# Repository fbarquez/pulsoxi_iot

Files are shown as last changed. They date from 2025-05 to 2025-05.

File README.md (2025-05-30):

# IoT-Based Pulse Oximeter with PIC16F1936/37 and ESP32











---

## Project Overview

This repository presents the development of a **microcontroller-based pulse oximeter** with wireless data transmission via Wi-Fi, intended for remote health monitoring. The system was designed as part of a Bachelor's thesis in **Information and Communication Technology Engineering** at HTW Berlin.

It measures **SpO₂ (blood oxygen saturation)** and **BPM (heart rate)** using optical sensing and analog signal conditioning. A **PIC16F1937** microcontroller digitizes the signals and transmits them via UART to an **ESP32-C6**, which uploads the data to **ThingSpeak** for real-time cloud visualization.

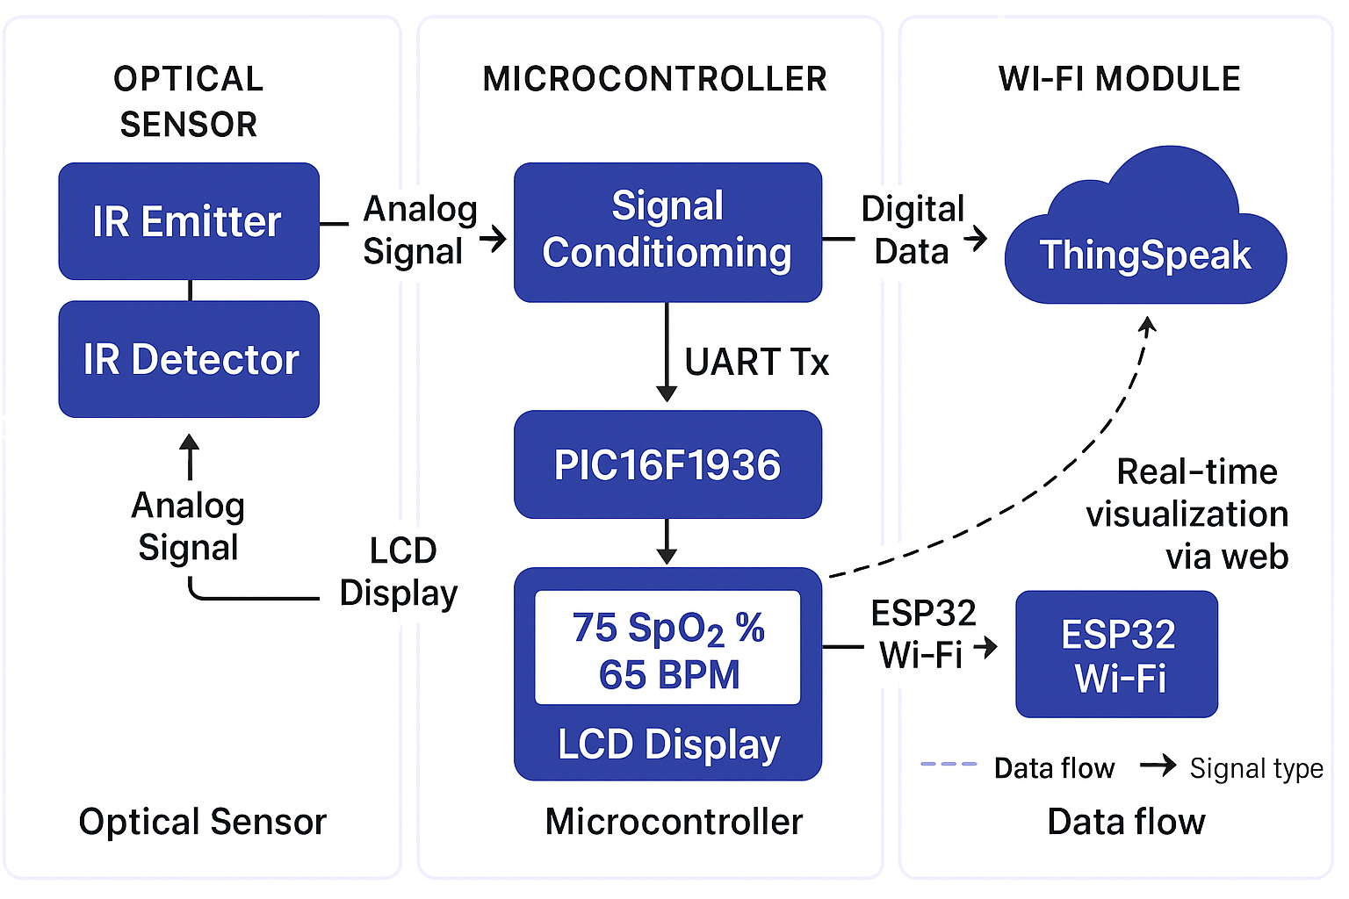
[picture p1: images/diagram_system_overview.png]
Project Overview


---

**View Full Thesis (Web Viewer)**: 
[Read the full thesis as images](https://fbarquez.github.io/pulsoxi_iot/thesis/index.html)

**Live Demonstration Video**: 
[▶ Watch on Dropbox](https://www.dropbox.com/scl/fi/jzmq0wq67i9w6cfi0vw9p/FernandoBarrigaVasquez_videodesProjekts.mp4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)

---

## Features

- Real-time SpO₂ and BPM measurement
- Modular signal processing: sensor input, analog conditioning, digitization
- Wireless data transmission via ESP32 and Wi-Fi
- ThingSpeak dashboard with live charts
- Local LCD display for instant readings
- Custom-designed PCBs using EAGLE

---

## Folder Structure

```
├── docs/                  # Thesis report and web materials
├── firmware/              # Embedded code for PIC and ESP32
│   ├── pic/
│   └── esp32/
├── hardware/              # Schematics and PCB files
├── images/                # Photos and diagrams
├── LICENSE
├── NOTICE.md
├── README.md
└── requirements.md
```

---

## System Architecture

The system is divided into three functional modules:
...

### 1. Analog Front-End (AFE)
- **Components**: IR + Red LEDs, BPW34 photodiode
- **Signal Conditioning**: Low-pass/high-pass filters, current-to-voltage converter, amplifier

### 2. Microcontroller Unit (MCU)
- **Microcontroller**: PIC16F1937 with ADC and UART
- **Tasks**: Signal digitization, data formatting, LCD display update

### 3. Connectivity & Visualization
- **ESP32-C6**: UART receiver, Wi-Fi client
- **Cloud**: ThingSpeak channel for live plotting

---

## Hardware Design

The hardware was developed using **Autodesk EAGLE** and includes:

- Modular PCBs for:
  - Signal conditioning
  - Optical sensor input
  - Power regulation
- Schematic and board files (`.sch` / `.brd`) available in `hardware/eagle/`
- Rendered images and PDFs in `hardware/pdf/`

---

## Firmware and Software

### PIC16F1937 Firmware

- Developed in C using **MPLAB X IDE** with **MCC**
- Core features:
  - ADC configuration
  - UART transmission to ESP32
  - LCD driver integration

 Path: `firmware/pic/oxi_spo2_firmware/`

### ESP32 UART Receiver

- Written in **Arduino framework**
- Connects via UART to PIC
- Transmits data to ThingSpeak over Wi-Fi

 Path: `firmware/esp32/usart_relay_thingspeak.ino`

---

## Data Transmission & Visualization

- **ThingSpeak** IoT platform:
  - Channel with 2 fields: SpO₂ (%) and BPM
  - Real-time data plotted in the dashboard

- **LCD Output**:
  - Displays BPM and oxygen level locally

---

## Requirements

- [MPLAB X IDE](https://www.microchip.com/en-us/tools-resources/develop/mplab-x-ide)
- [MCC (Code Configurator)](https://www.microchip.com/mplab/mplab-code-configurator)
- [Arduino IDE](https://www.arduino.cc/en/software)
- ESP32 board support package
- [ThingSpeak account](https://thingspeak.com)

---

## Usage Instructions

### 1. Clone the repository

```bash
git clone https://github.com/yourusername/SpO2-Monitor-Project.git
cd SpO2-Monitor-Project
```

### 2. PIC Firmware

- Open `firmware/pic/oxi_spo2_firmware/` in MPLAB X
- Compile and flash to the PIC16F1937

### 3. ESP32 Code

- Open `firmware/esp32/usart_relay_thingspeak.ino` in Arduino IDE
- Configure your Wi-Fi credentials and ThingSpeak API key
- Upload to your ESP32 board

### 4. Dashboard

- Access your ThingSpeak channel to monitor live data
- Optionally view readings on the 16x2 LCD display

---

## License & Legal

This repository is provided **for educational and demonstration purposes only**.

> Not licensed for reuse, redistribution, or commercial use.

All content © 2024 fbarquez. 
See [`LICENSE`](LICENSE) for more details.

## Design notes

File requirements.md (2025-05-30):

# Project Requirements

This document lists all the tools, libraries, and platforms required to build, upload, and run the Pulse Oximeter project.

---

## Hardware Requirements

- **Microcontroller**: PIC16F1937
- **Wi-Fi Module**: ESP32-C6
- **Sensors**:
  - BPW34 photodiode
  - IR and RED LEDs
- **Display**: 16x2 LCD (HD44780 compatible)

---

## Development Tools

### For PIC16F1937 (Firmware)

- [MPLAB X IDE](https://www.microchip.com/en-us/tools-resources/develop/mplab-x-ide) (v6.0 or later)
- [MPLAB XC8 Compiler](https://www.microchip.com/en-us/tools-resources/develop/mplab-xc-compilers) (v2.40 or later)
- [MCC - MPLAB Code Configurator](https://www.microchip.com/mplab/mplab-code-configurator)

### For ESP32 (Wi-Fi Transmitter)

- [Arduino IDE](https://www.arduino.cc/en/software) (v2.0 or later)
- ESP32 Board Support via Board Manager  
  (Install via: `https://raw.githubusercontent.com/espressif/arduino-esp32/gh-pages/package_esp32_index.json`)
- Required Arduino libraries:
  - `WiFi.h`
  - `HTTPClient.h`

---

## Hardware Design

- [Autodesk EAGLE](https://www.autodesk.com/products/eagle/overview) (v9.6 or later)

---

## Online Services

- [ThingSpeak](https://thingspeak.com) IoT platform
  - One channel with at least 2 fields: SpO₂ and BPM
  - Optional: API Key for write access

- [GitHub Pages](https://pages.github.com/) for hosting the presentation page (optional)

---

## Optional Tools

- [Proteus / LTspice / Falstad] (for circuit simulation if used during development)
- [Markdown Preview](https://marketplace.visualstudio.com/items?itemName=shd101wyy.markdown-preview-enhanced) (for README visualization)

---

## Notes

- Ensure all USB drivers for PICkit or ESP32 are properly installed.
- Internet access is required for data upload to ThingSpeak.

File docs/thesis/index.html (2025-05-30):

# Bachelor Thesis: IoT Pulse Oximeter

Presented by fbarquez – HTW Berlin, 2024

This viewer displays each page of the thesis as an image with watermarks for privacy.

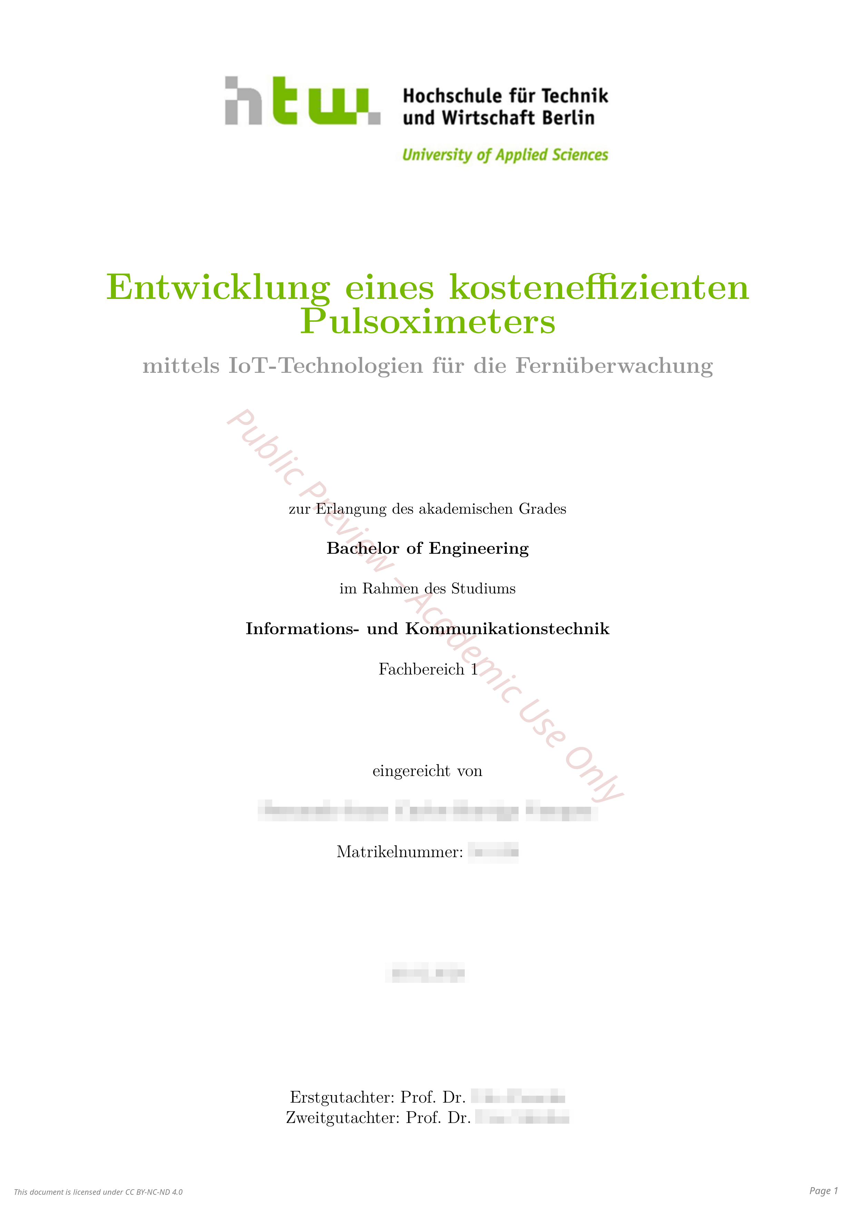
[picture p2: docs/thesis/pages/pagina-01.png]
Thesis page 1 – Pulse Oximeter Project
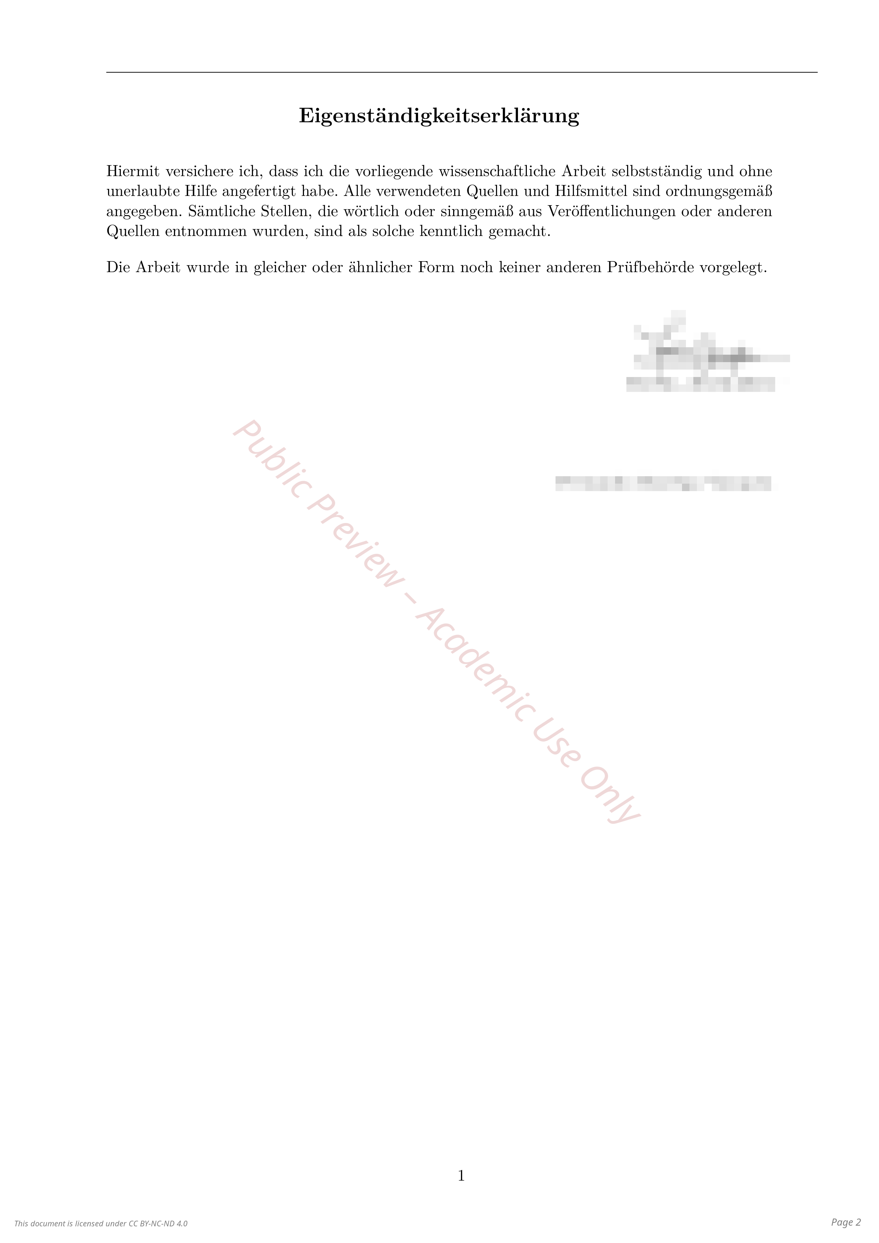
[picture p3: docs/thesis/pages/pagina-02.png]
Thesis page 2 – Pulse Oximeter Project
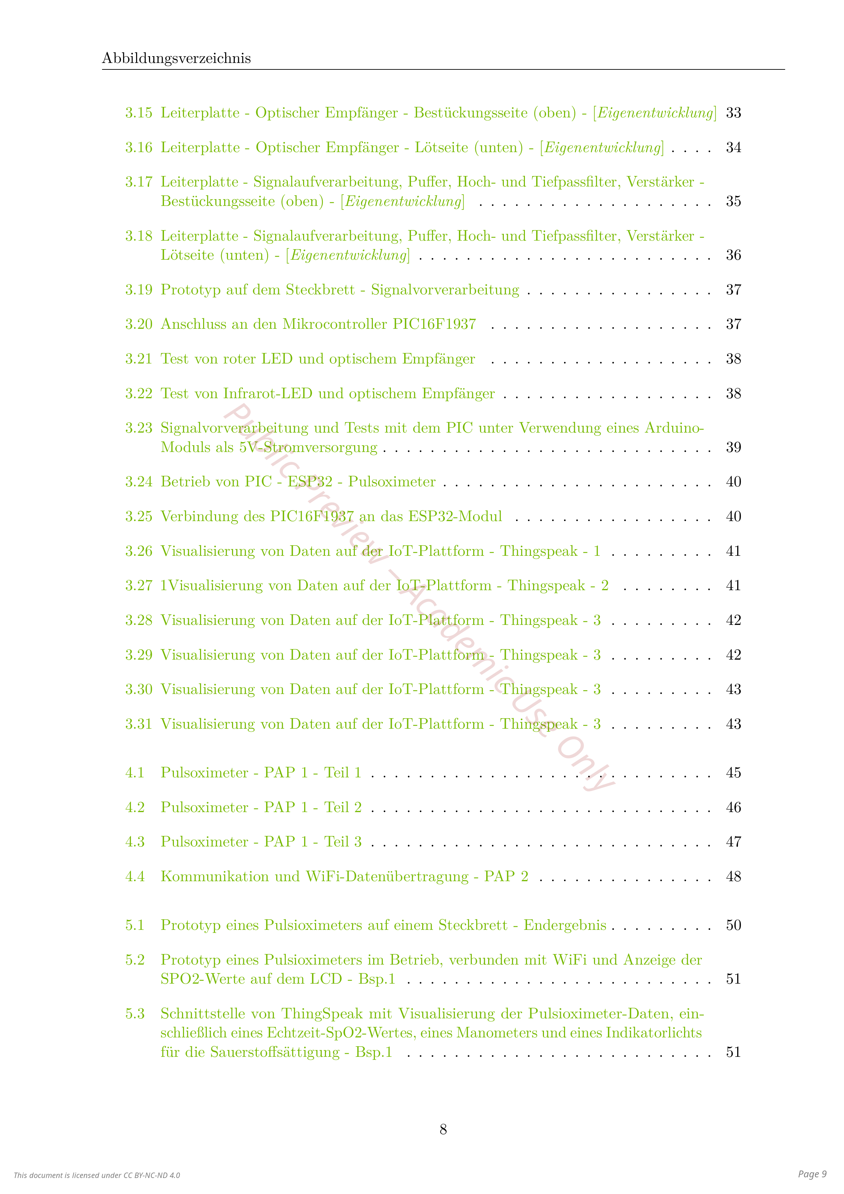
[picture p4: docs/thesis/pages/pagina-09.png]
Thesis page 9 – Pulse Oximeter Project
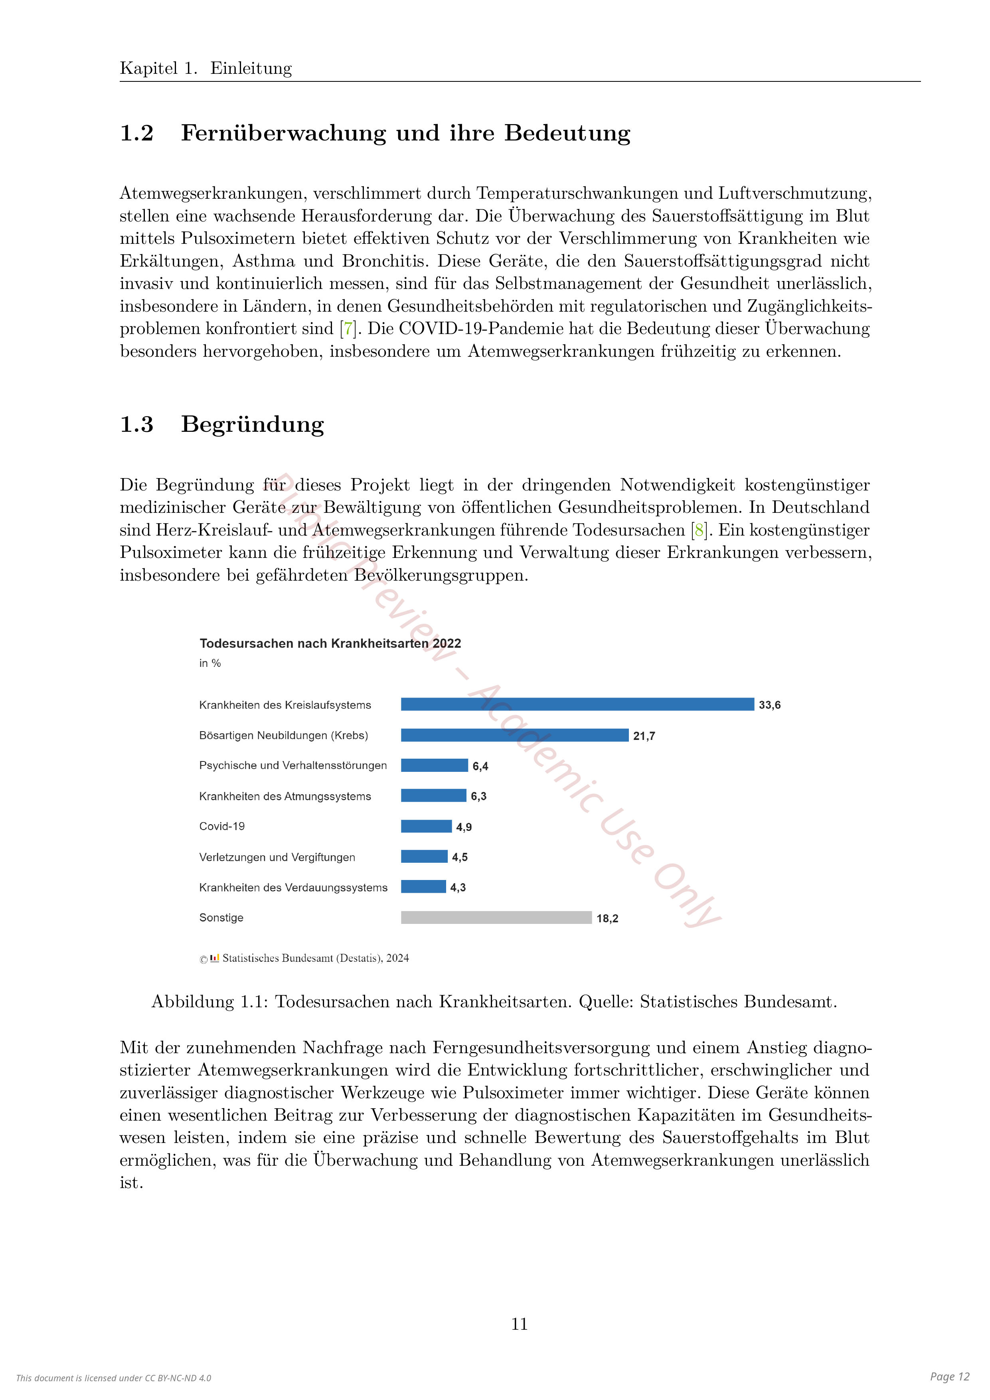
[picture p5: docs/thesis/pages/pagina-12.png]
Thesis page 12 – Pulse Oximeter Project
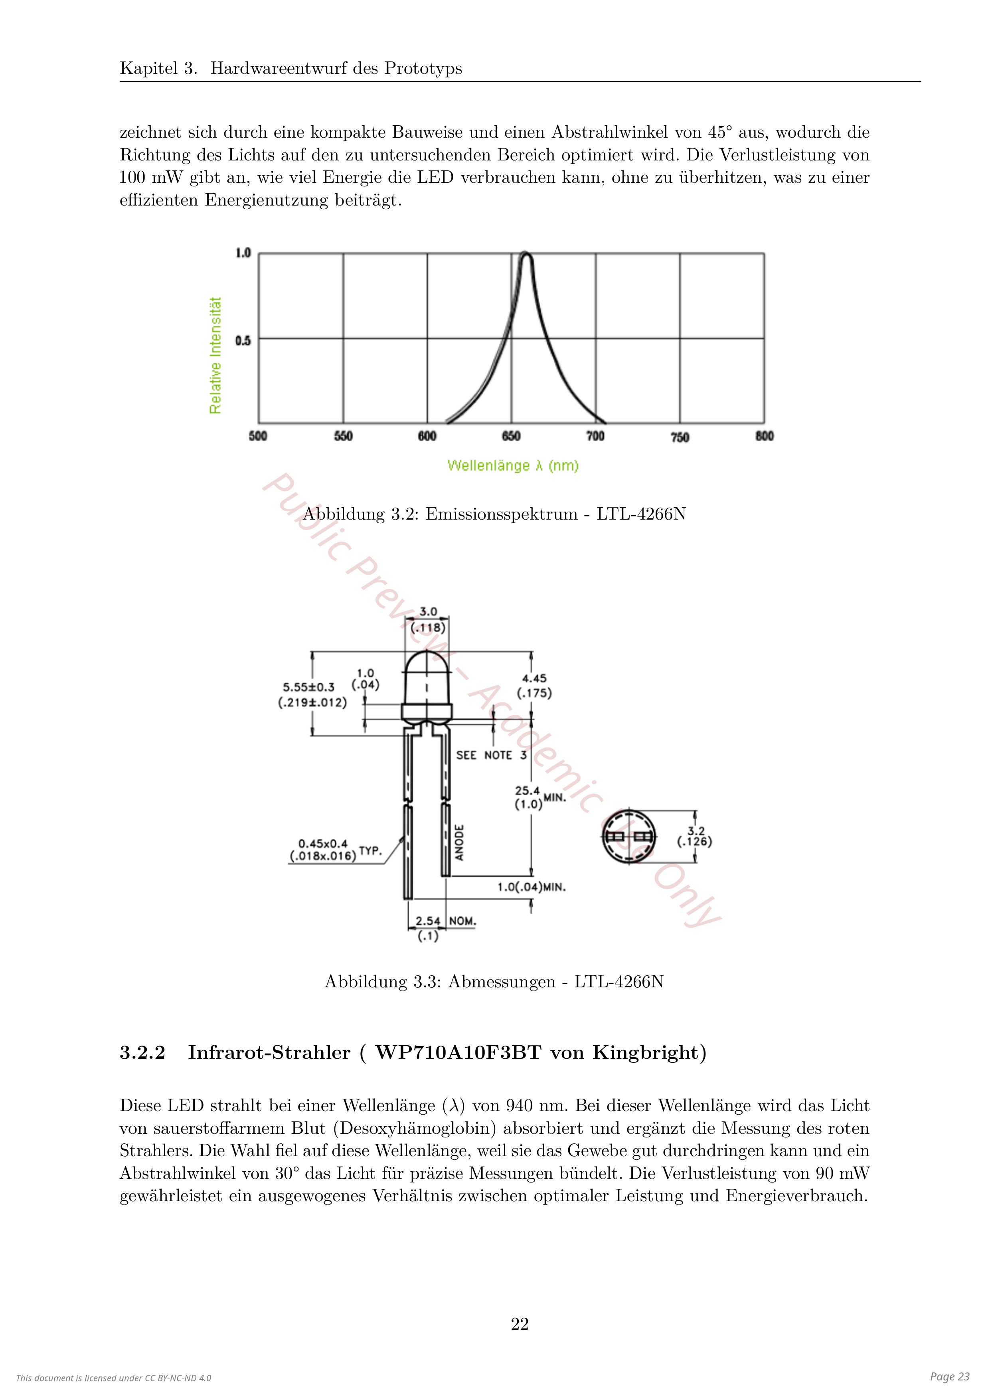
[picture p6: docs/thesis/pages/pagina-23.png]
Thesis page 23 – Pulse Oximeter Project
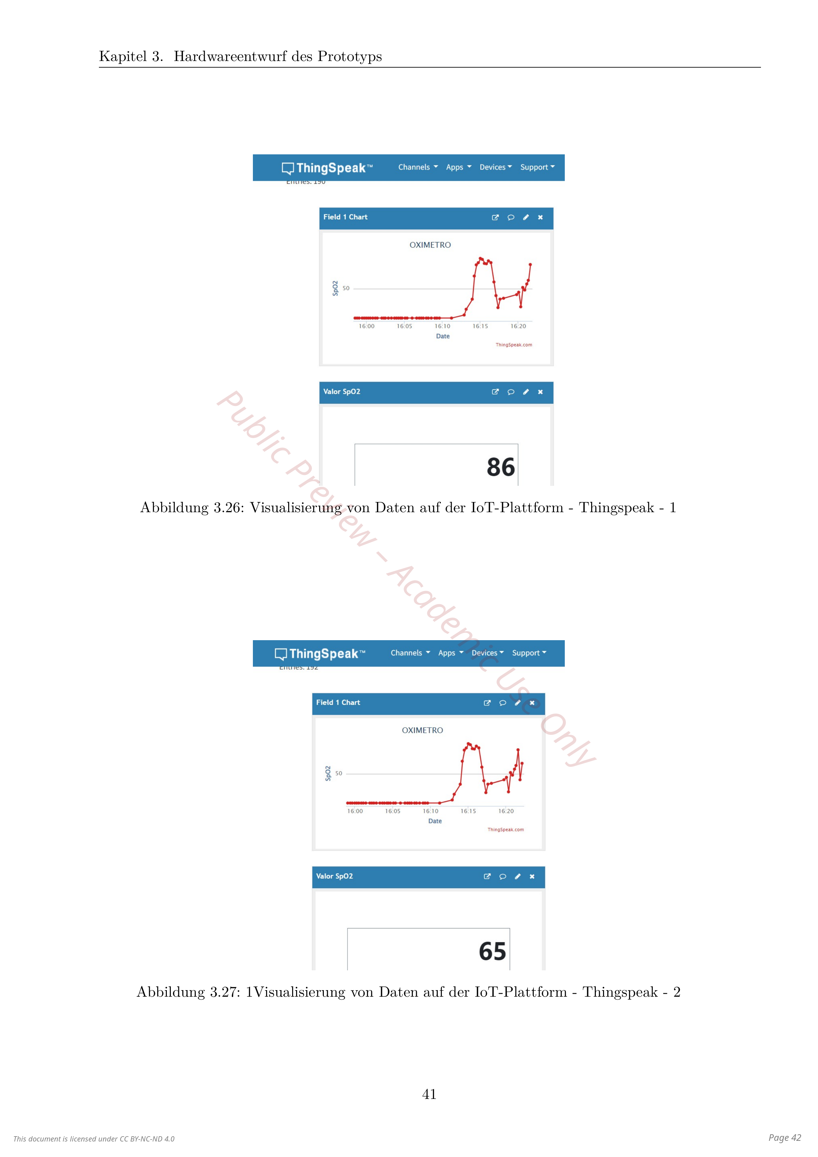
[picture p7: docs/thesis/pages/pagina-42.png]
Thesis page 42 – Pulse Oximeter Project
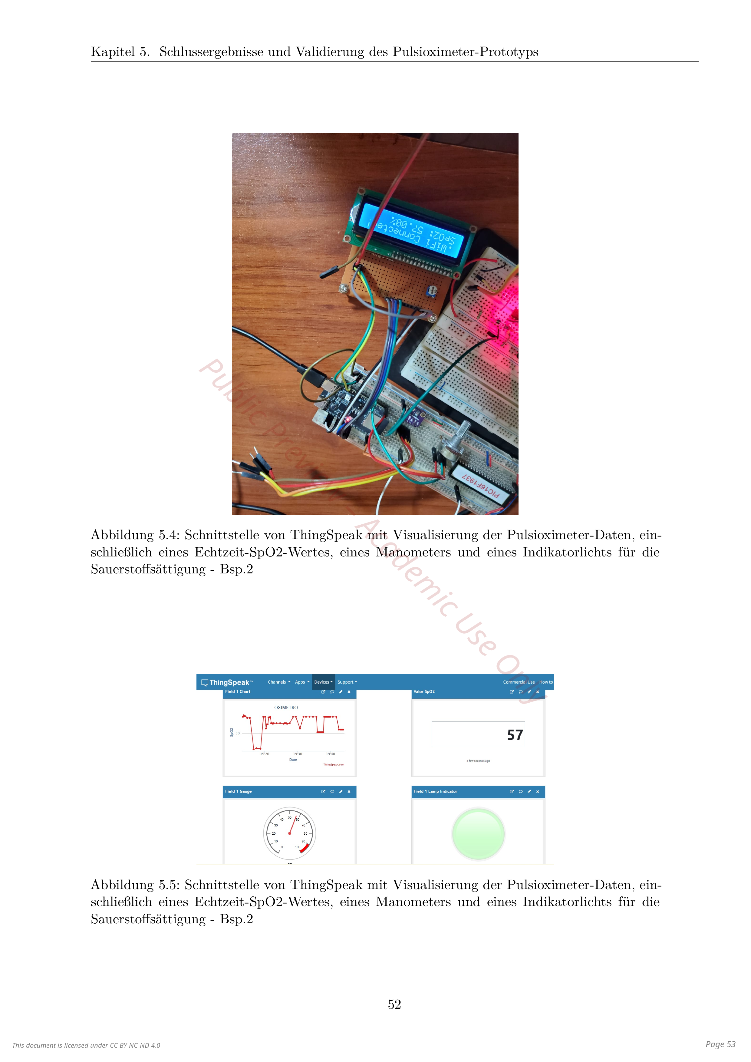
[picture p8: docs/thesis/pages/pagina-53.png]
Thesis page 53 – Pulse Oximeter Project
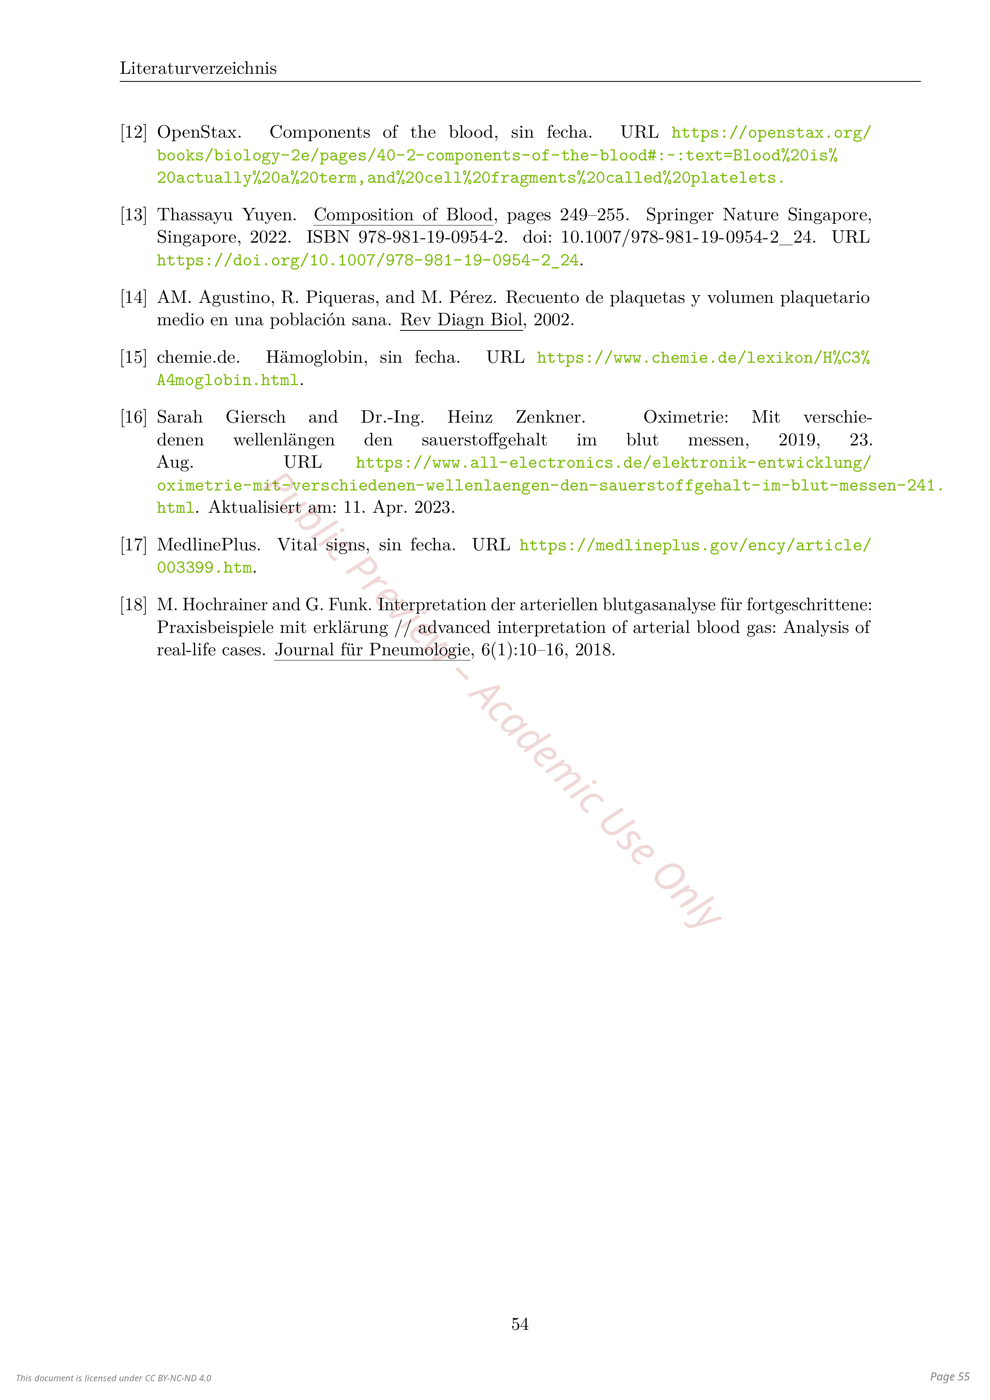
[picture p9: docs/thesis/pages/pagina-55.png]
Thesis page 55 – Pulse Oximeter Project
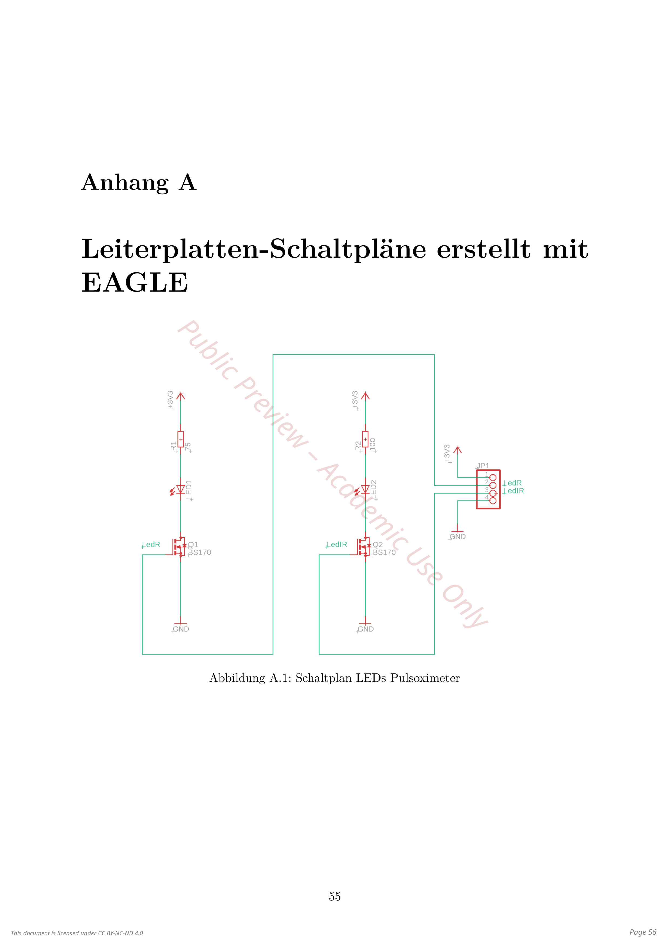
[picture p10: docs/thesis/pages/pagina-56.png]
Thesis page 56 – Pulse Oximeter Project
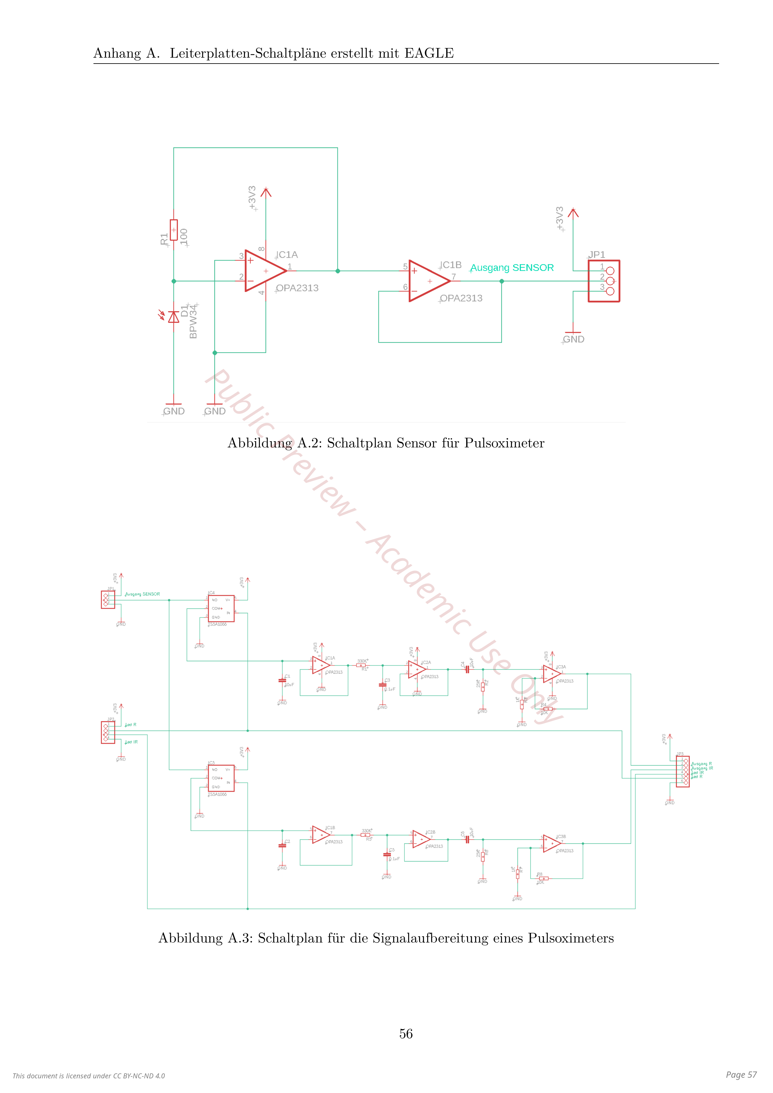
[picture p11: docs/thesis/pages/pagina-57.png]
Thesis page 57 – Pulse Oximeter Project
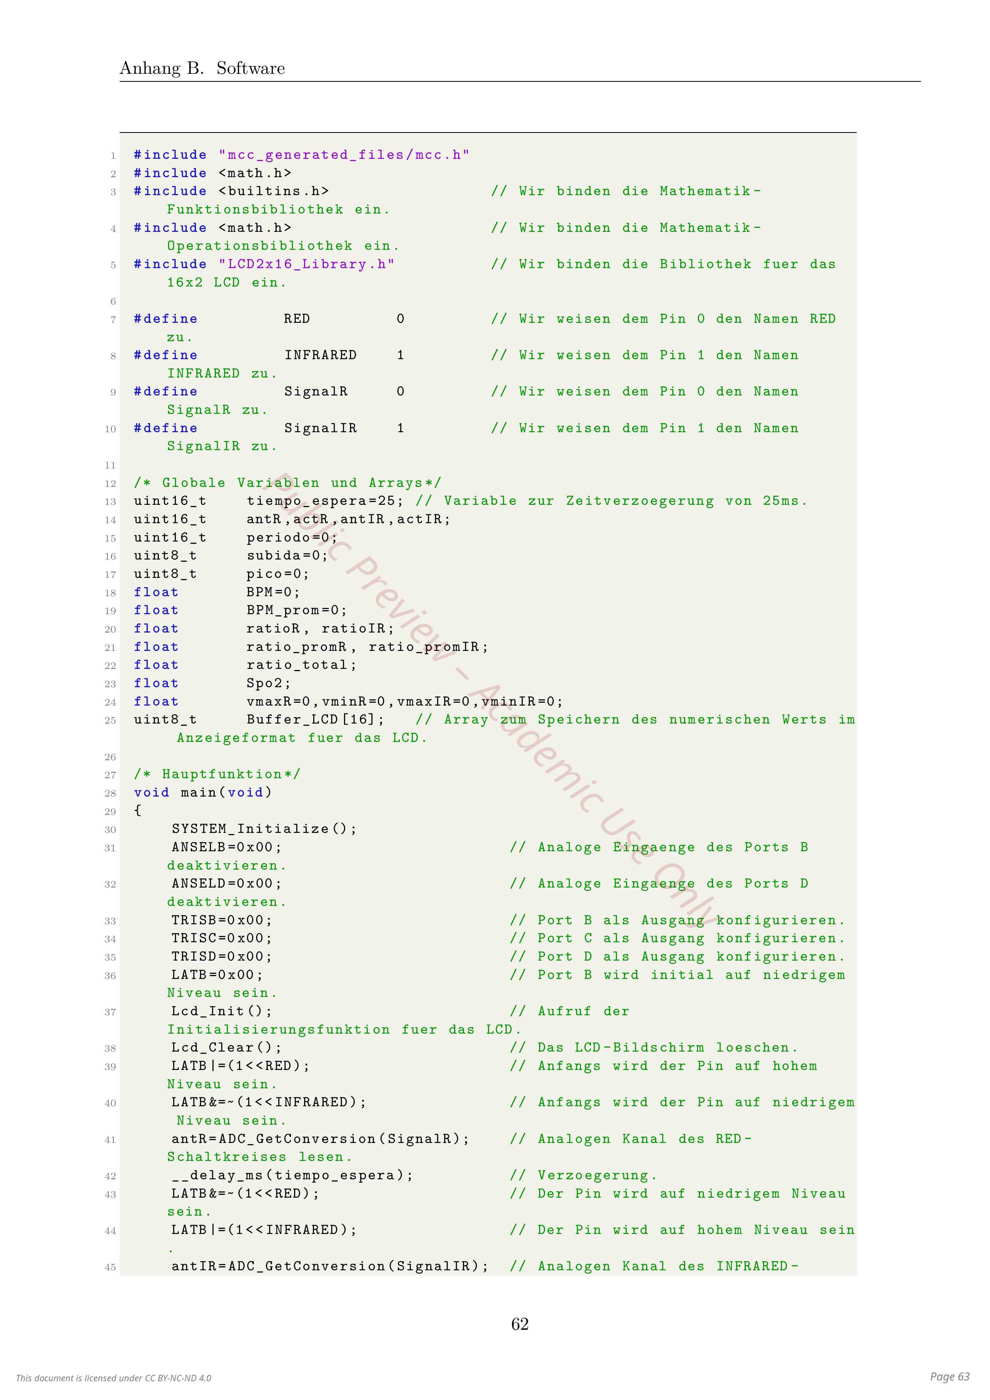
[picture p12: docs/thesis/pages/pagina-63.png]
Thesis page 63 – Pulse Oximeter Project
  Thesis page 3 – Pulse Oximeter Project Thesis page 4 – Pulse Oximeter Project Thesis page 5 – Pulse Oximeter Project Thesis page 6 – Pulse Oximeter Project Thesis page 7 – Pulse Oximeter Project Thesis page 8 – Pulse Oximeter Project  Thesis page 10 – Pulse Oximeter Project Thesis page 11 – Pulse Oximeter Project  Thesis page 13 – Pulse Oximeter Project Thesis page 14 – Pulse Oximeter Project Thesis page 15 – Pulse Oximeter Project Thesis page 16 – Pulse Oximeter Project Thesis page 17 – Pulse Oximeter Project Thesis page 18 – Pulse Oximeter Project Thesis page 19 – Pulse Oximeter Project Thesis page 20 – Pulse Oximeter Project Thesis page 21 – Pulse Oximeter Project Thesis page 22 – Pulse Oximeter Project  Thesis page 24 – Pulse Oximeter Project Thesis page 25 – Pulse Oximeter Project Thesis page 26 – Pulse Oximeter Project Thesis page 27 – Pulse Oximeter Project Thesis page 28 – Pulse Oximeter Project Thesis page 29 – Pulse Oximeter Project Thesis page 30 – Pulse Oximeter Project Thesis page 31 – Pulse Oximeter Project Thesis page 32 – Pulse Oximeter Project Thesis page 33 – Pulse Oximeter Project Thesis page 34 – Pulse Oximeter Project Thesis page 35 – Pulse Oximeter Project Thesis page 36 – Pulse Oximeter Project Thesis page 37 – Pulse Oximeter Project Thesis page 38 – Pulse Oximeter Project Thesis page 39 – Pulse Oximeter Project Thesis page 40 – Pulse Oximeter Project Thesis page 41 – Pulse Oximeter Project  Thesis page 43 – Pulse Oximeter Project Thesis page 44 – Pulse Oximeter Project Thesis page 45 – Pulse Oximeter Project Thesis page 46 – Pulse Oximeter Project Thesis page 47 – Pulse Oximeter Project Thesis page 48 – Pulse Oximeter Project Thesis page 49 – Pulse Oximeter Project Thesis page 50 – Pulse Oximeter Project Thesis page 51 – Pulse Oximeter Project Thesis page 52 – Pulse Oximeter Project  Thesis page 54 – Pulse Oximeter Project    Thesis page 58 – Pulse Oximeter Project Thesis page 59 – Pulse Oximeter Project Thesis page 60 – Pulse Oximeter Project Thesis page 61 – Pulse Oximeter Project Thesis page 62 – Pulse Oximeter Project  Thesis page 64 – Pulse Oximeter Project Thesis page 65 – Pulse Oximeter Project Thesis page 66 – Pulse Oximeter Project Thesis page 67 – Pulse Oximeter Project Thesis page 68 – Pulse Oximeter Project

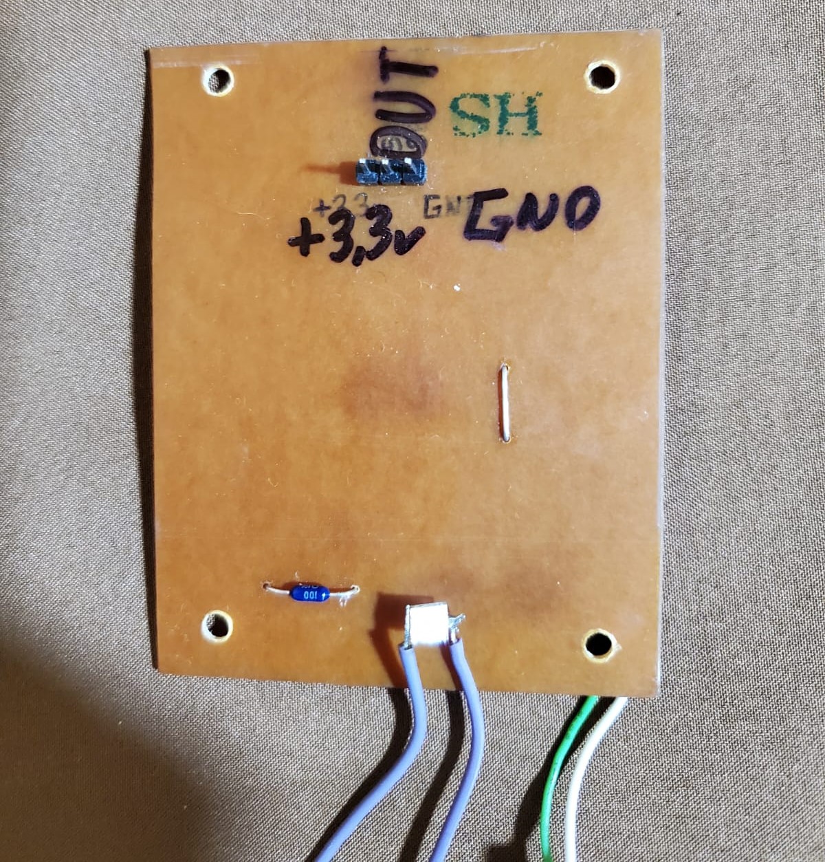
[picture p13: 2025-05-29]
images/PCB/ReceptorOptico_PCB_elaboracionpropia.jpg

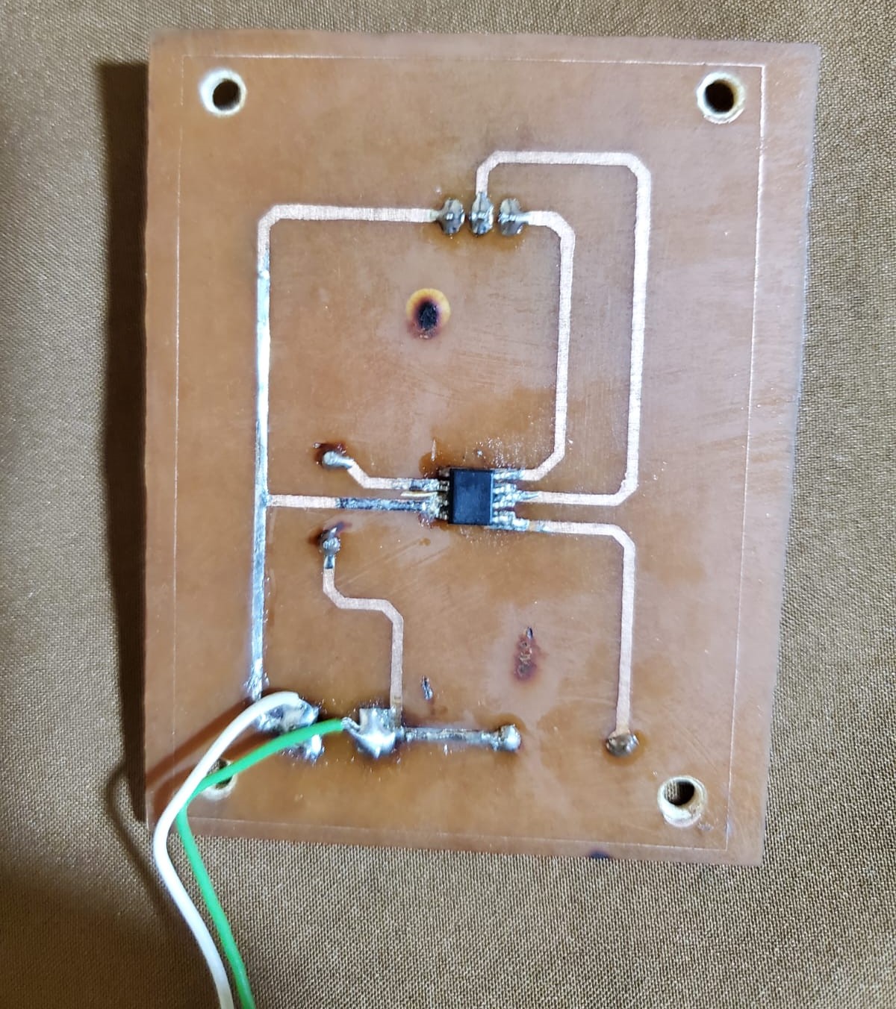
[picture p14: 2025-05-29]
images/PCB/ReceptorOptico_PCB_elaboracionpropia_2.jpg

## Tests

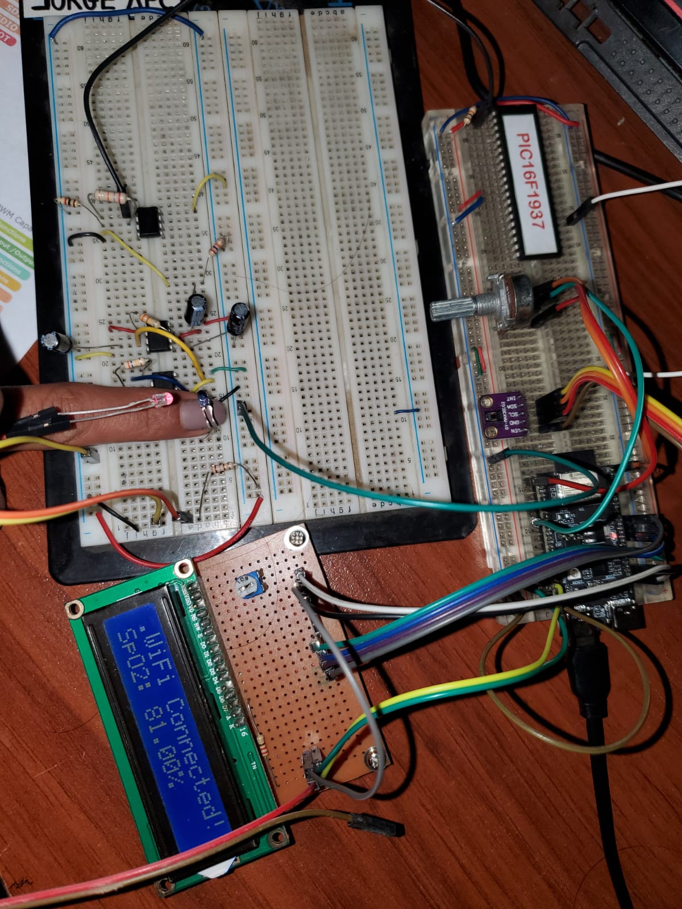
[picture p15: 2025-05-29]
images/pruebadequetodofunciona.jpg

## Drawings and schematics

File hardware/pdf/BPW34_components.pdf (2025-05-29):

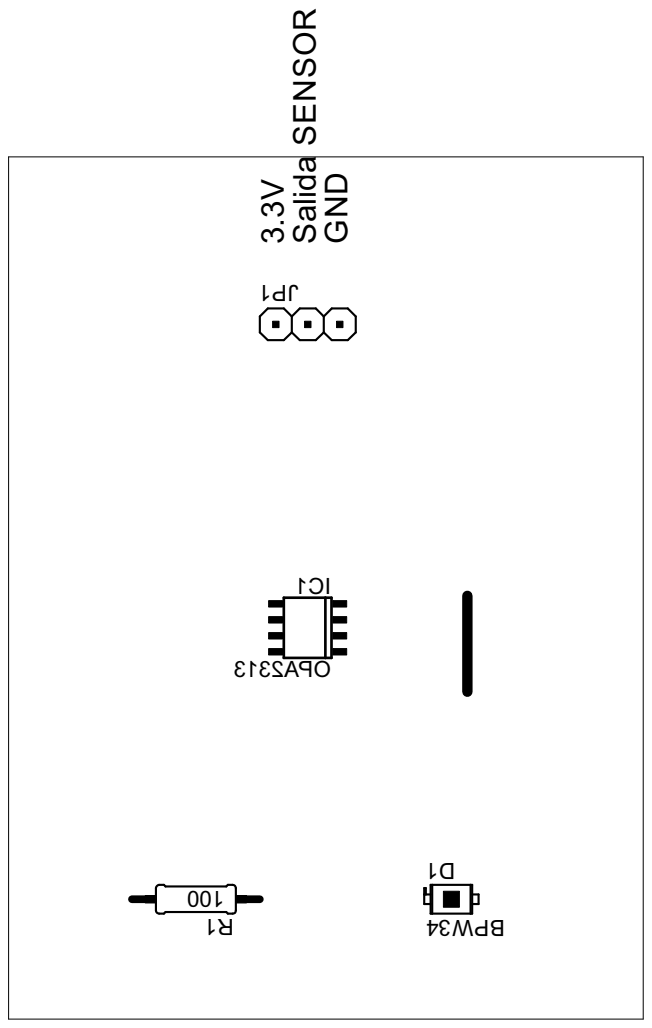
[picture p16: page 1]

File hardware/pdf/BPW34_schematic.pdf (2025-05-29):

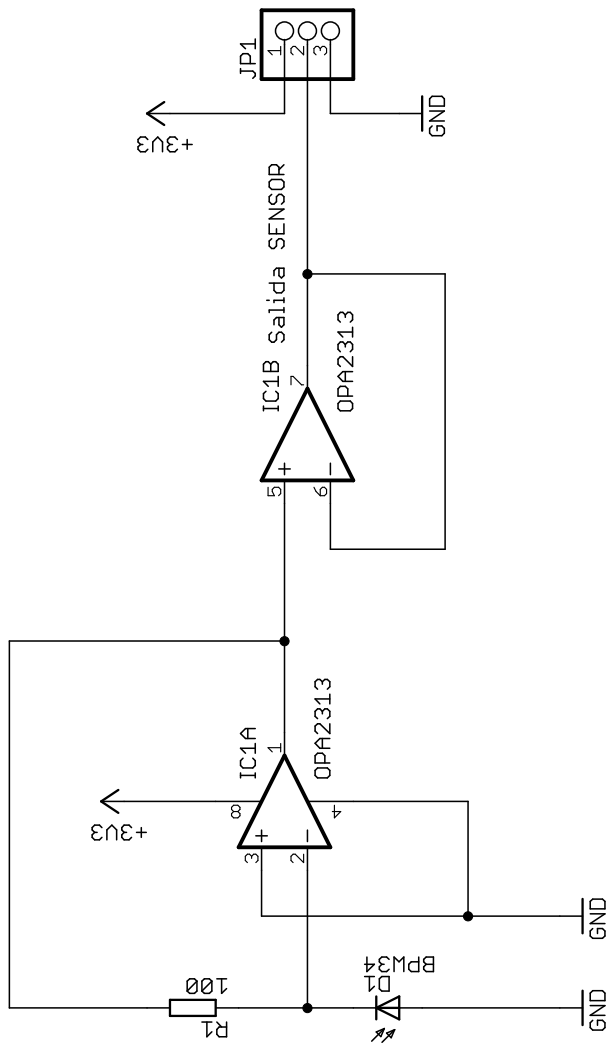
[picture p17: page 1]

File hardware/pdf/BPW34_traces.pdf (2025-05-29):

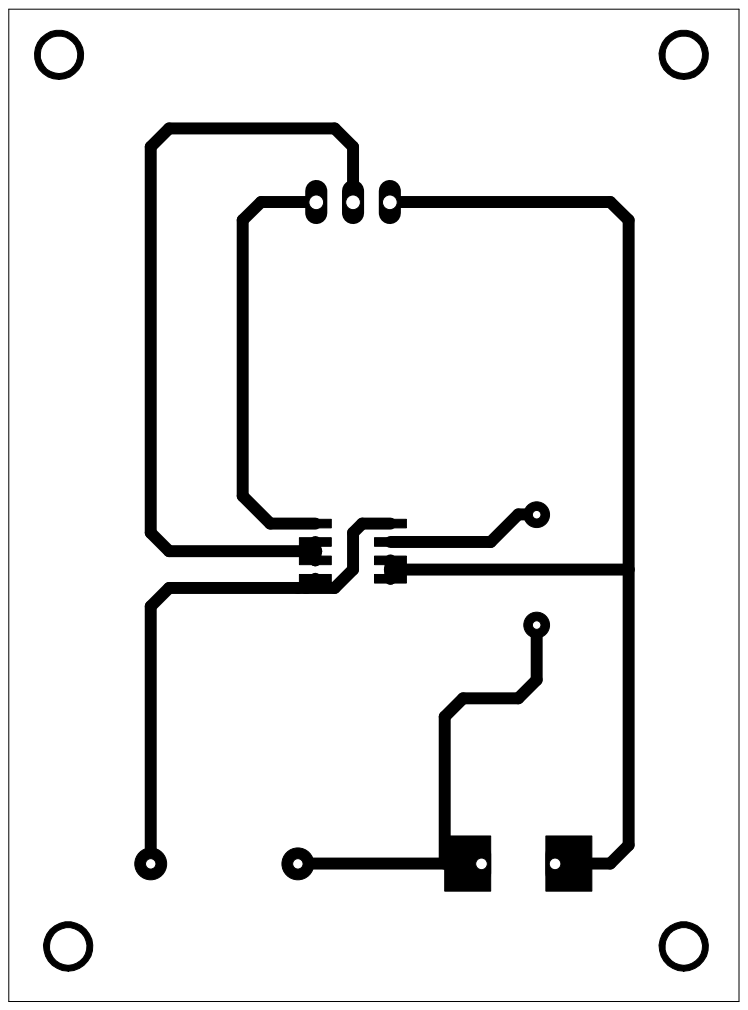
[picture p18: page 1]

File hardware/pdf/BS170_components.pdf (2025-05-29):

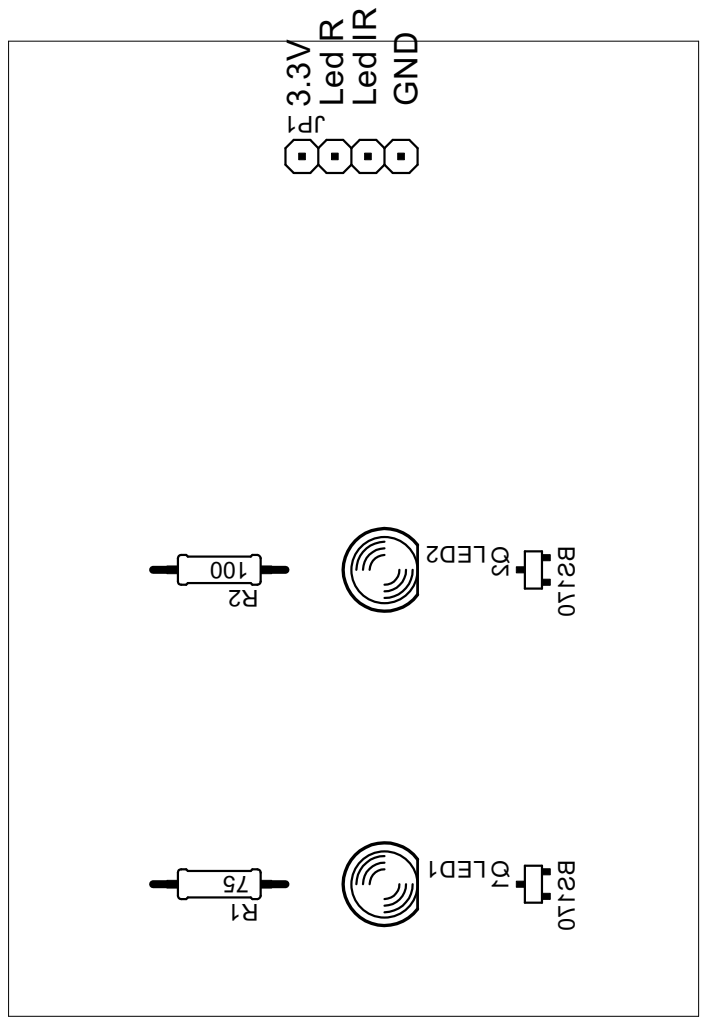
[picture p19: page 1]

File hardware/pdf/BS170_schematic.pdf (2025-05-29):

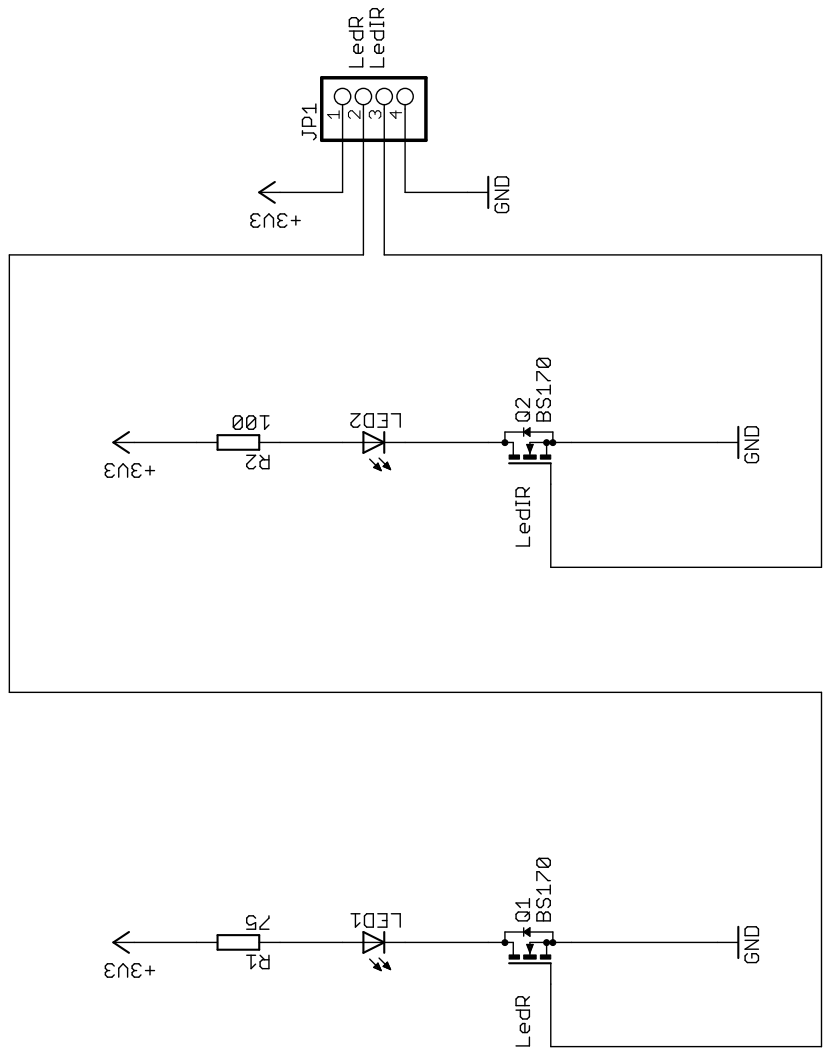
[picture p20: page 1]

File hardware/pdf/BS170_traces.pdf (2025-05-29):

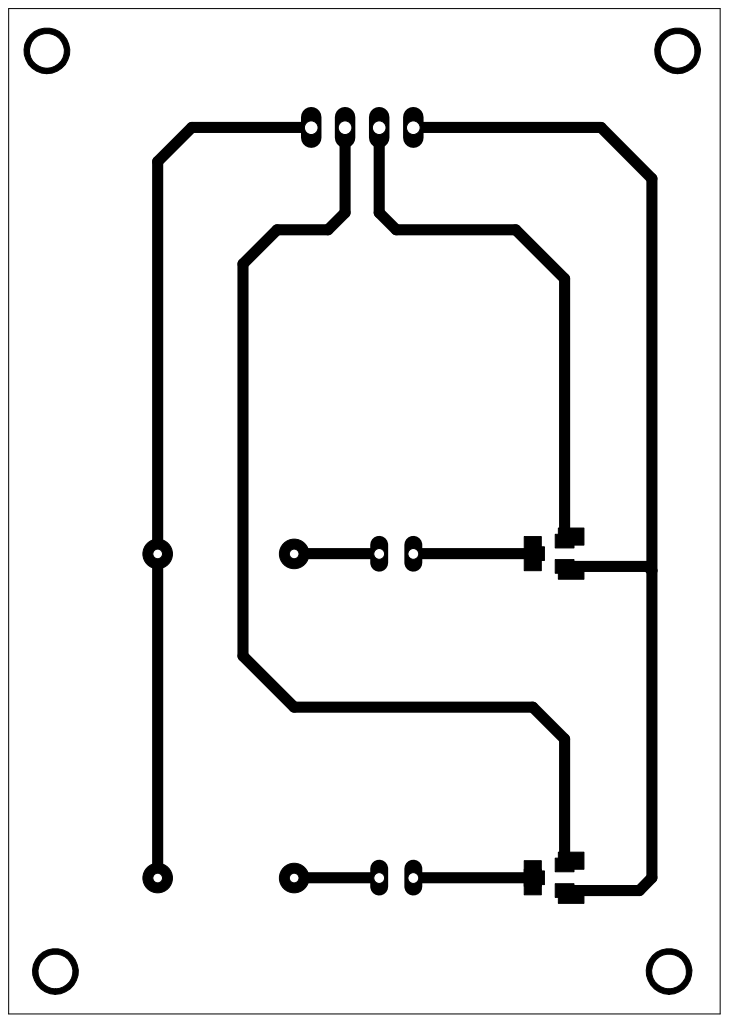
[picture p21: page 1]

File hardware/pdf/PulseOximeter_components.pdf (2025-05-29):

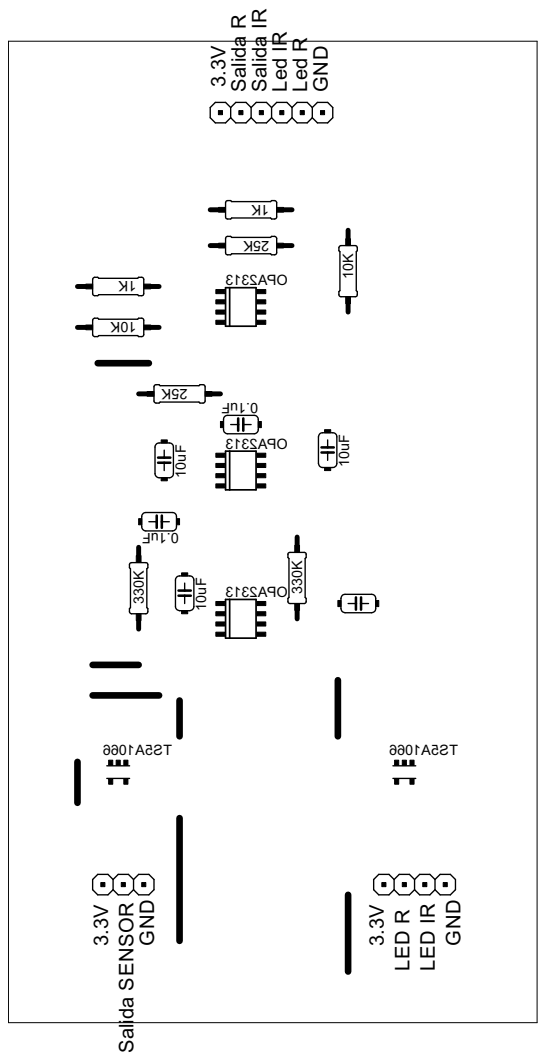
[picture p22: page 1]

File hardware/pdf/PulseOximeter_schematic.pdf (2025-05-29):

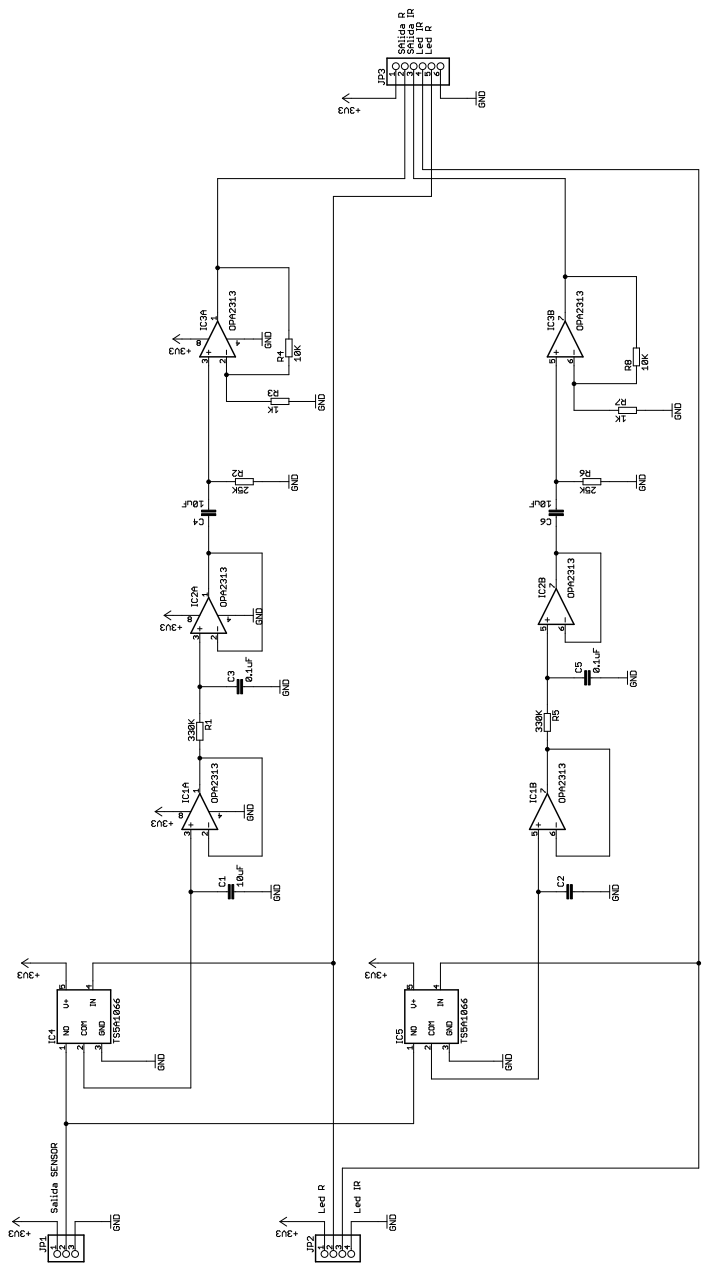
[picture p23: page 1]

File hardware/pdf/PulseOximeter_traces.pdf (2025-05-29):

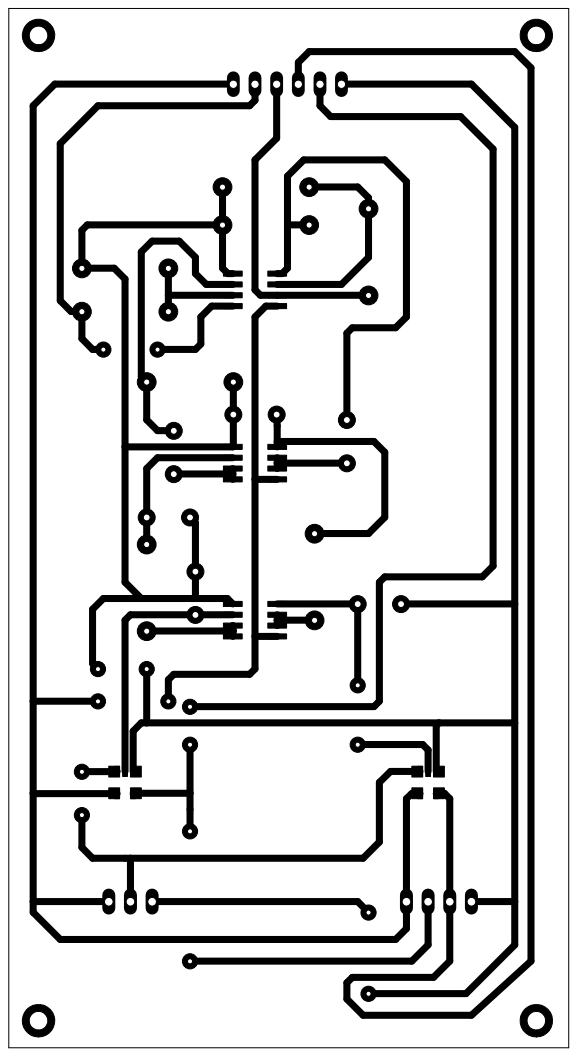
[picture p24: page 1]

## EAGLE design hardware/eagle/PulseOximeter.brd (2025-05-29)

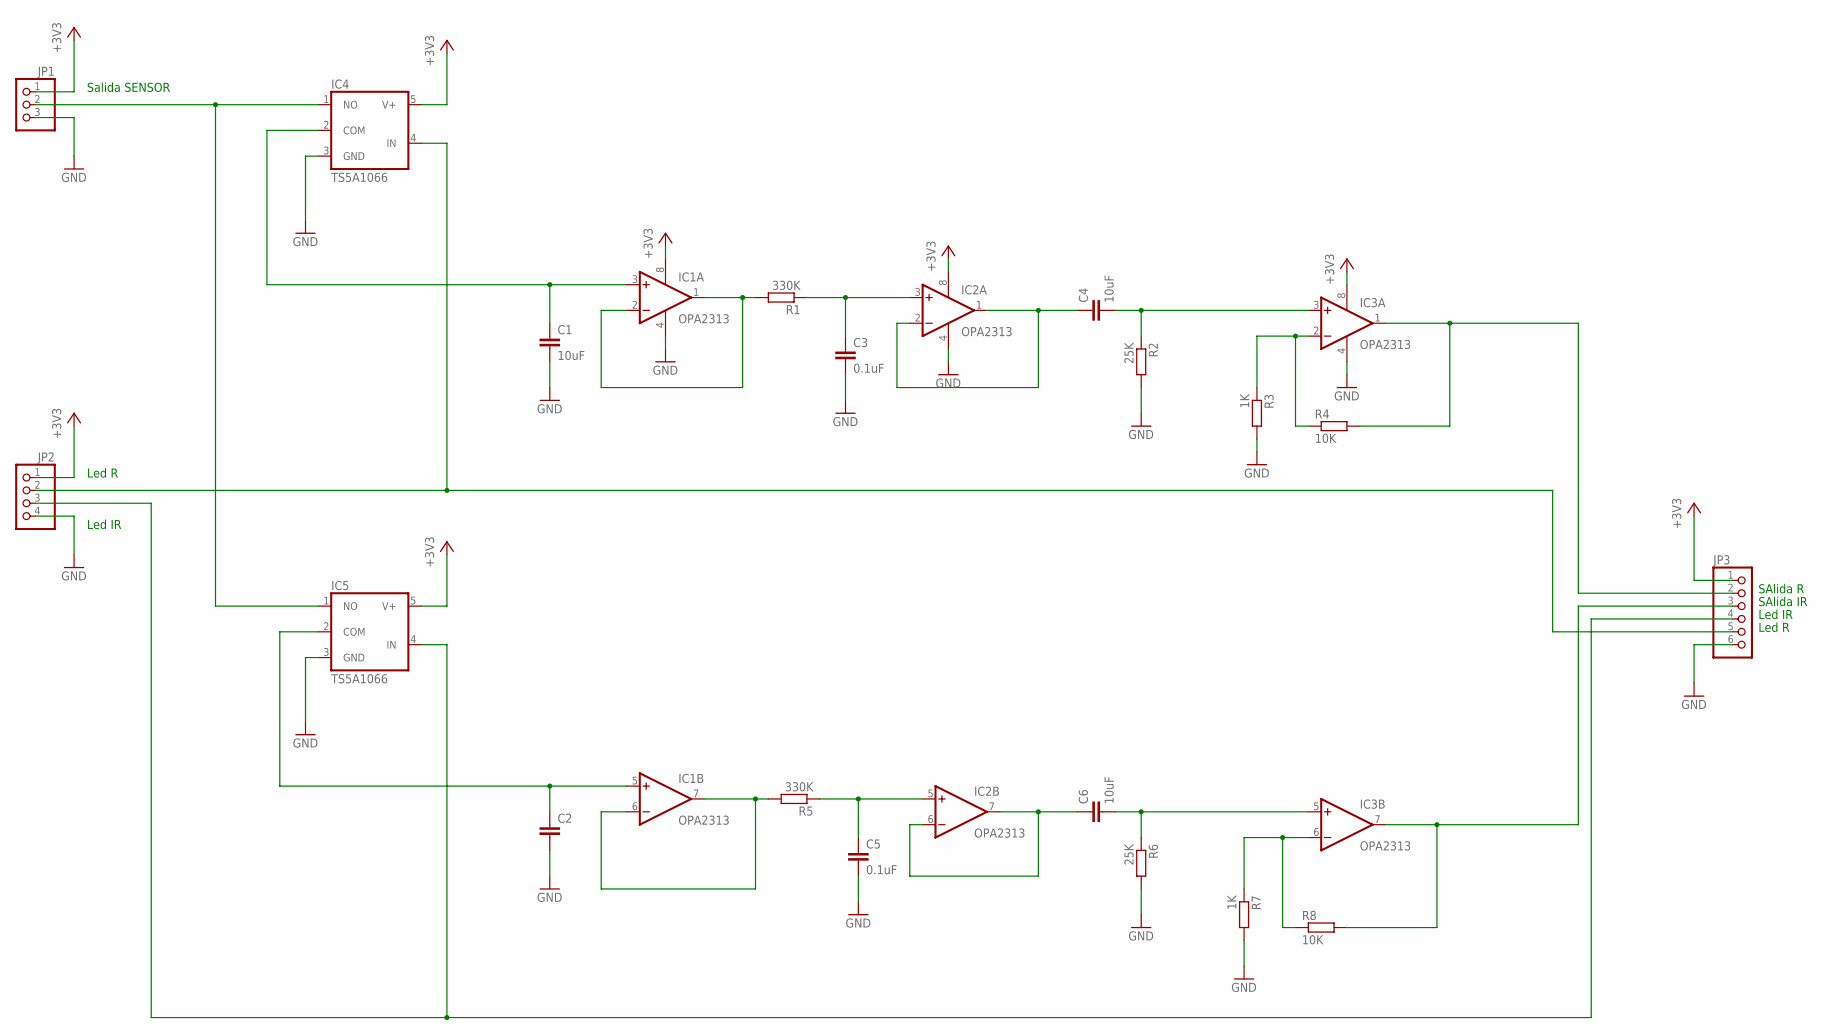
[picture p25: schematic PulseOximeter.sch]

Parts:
C1, C4, C6: 10uF; C050-024X044
C2: C-EU050-024X044; C050-024X044
C3, C5: 0.1uF; C050-024X044
IC1, IC2, IC3: OPA2313; SO08
IC4, IC5: TS5A1066; SOT25
JP1: PINHD-1X3; 1X03
JP2: PINHD-1X4; 1X04
JP3: PINHD-1X6; 1X06
R1, R5: 330K; 0207/10
R2, R6: 25K; 0207/10
R3, R7: 1K; 0207/10
R4, R8: 10K; 0207/10

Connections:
+3V3: IC1.8 (V+), IC2.8 (V+), IC3.8 (V+), IC4.5 (V+), IC5.5 (V+), JP1.1, JP2.1, JP3.1
GND: C1.2, C2.2, C3.2, C5.2, IC1.4 (V-), IC2.4 (V-), IC3.4 (V-), IC4.3 (GND), IC5.3 (GND), JP1.3, JP2.4, JP3.6, R2.2, R3.2, R6.2, R7.2
unnamed: IC4.1 (NO), IC5.1 (NO), JP1.2
unnamed: IC4.4 (IN), JP2.2, JP3.5
unnamed: IC5.4 (IN), JP2.3, JP3.4
unnamed: C1.1, IC1.3 (+IN), IC4.2 (COM)
unnamed: C2.1, IC1.5 (+IN), IC5.2 (COM)
unnamed: C3.1, IC2.3 (+IN), R1.1
unnamed: IC1.1 (OUT), IC1.2 (-IN), R1.2
unnamed: C4.1, IC2.1 (OUT), IC2.2 (-IN)
unnamed: C4.2, IC3.3 (+IN), R2.1
unnamed: IC3.2 (-IN), R3.1, R4.1
unnamed: IC3.1 (OUT), JP3.2, R4.2
unnamed: IC1.6 (-IN), IC1.7 (OUT), R5.2
unnamed: C5.1, IC2.5 (+IN), R5.1
unnamed: C6.1, IC2.6 (-IN), IC2.7 (OUT)
unnamed: C6.2, IC3.5 (+IN), R6.1
unnamed: IC3.6 (-IN), R7.1, R8.1
unnamed: IC3.7 (OUT), JP3.3, R8.2

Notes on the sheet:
Salida SENSOR
Led IR
Led R
SAlida R
SAlida IR

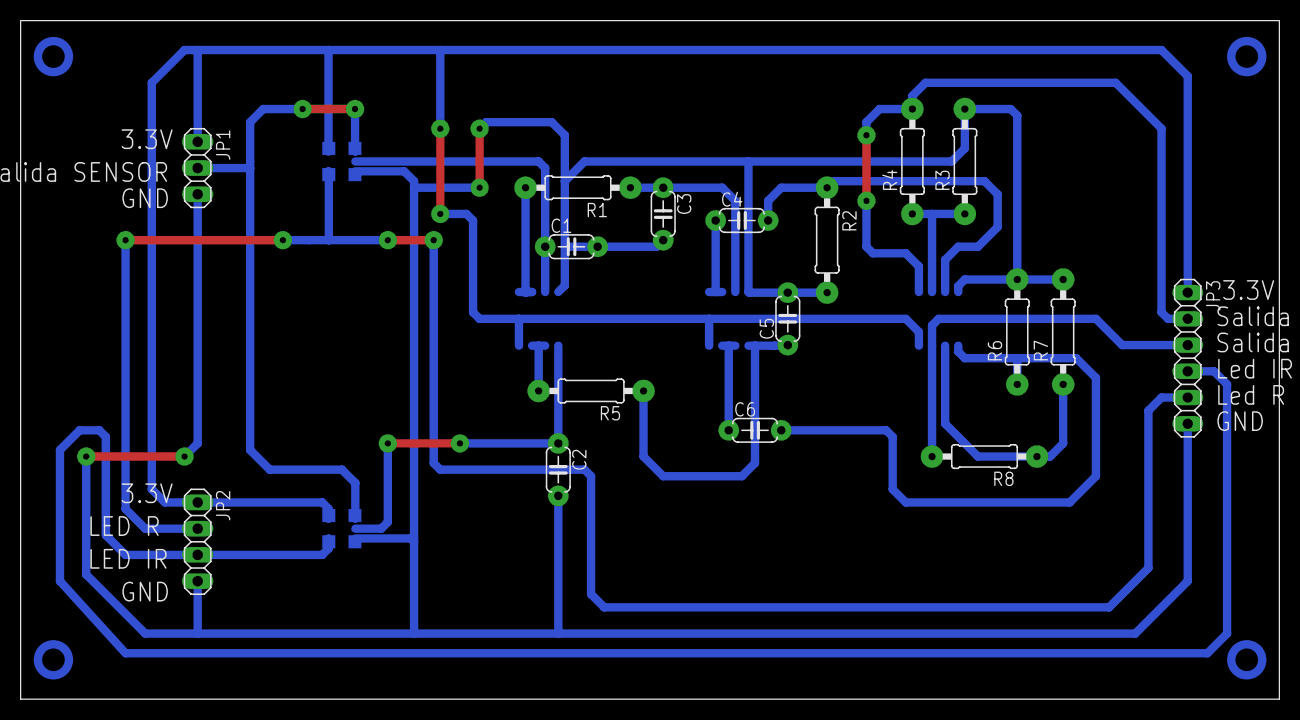
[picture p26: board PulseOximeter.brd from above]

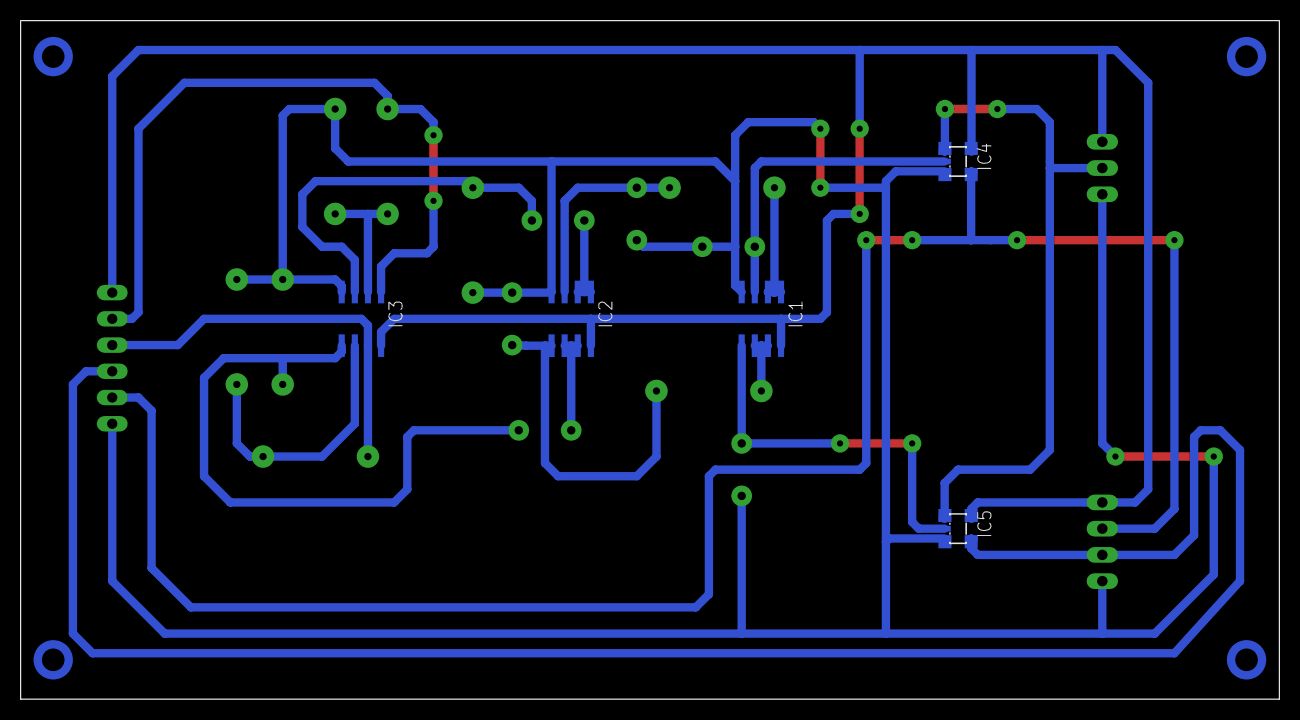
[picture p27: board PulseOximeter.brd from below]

Board: 2 copper layers, 121.9 x 65.7 mm, 22 parts (5 on the bottom side), 19 nets.

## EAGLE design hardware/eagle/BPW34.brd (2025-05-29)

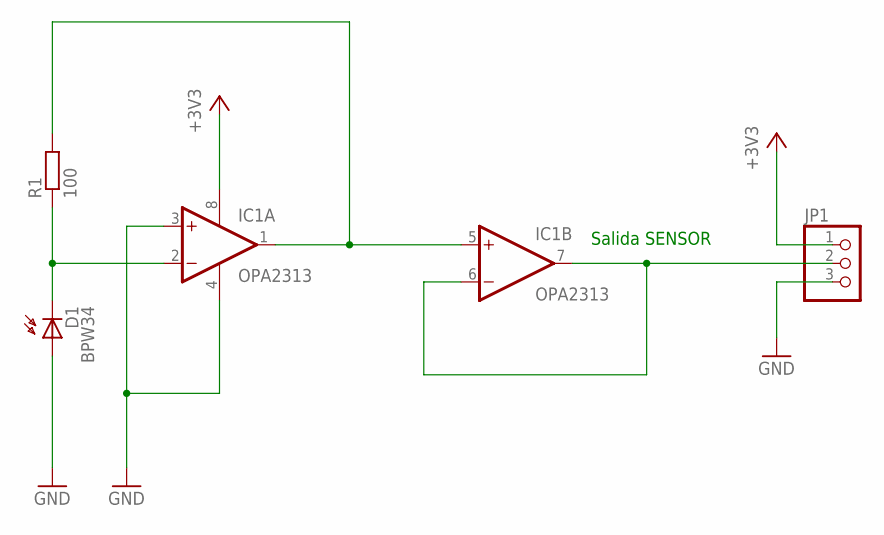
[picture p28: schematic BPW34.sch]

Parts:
D1: BPW34; BPW32
IC1: OPA2313; SO08
JP1: PINHD-1X3; 1X03
R1: 100; 0207/10

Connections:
+3V3: IC1.8 (V+), JP1.1
GND: D1.A, IC1.3 (+IN), IC1.4 (V-), JP1.3
unnamed: IC1.1 (OUT), IC1.5 (+IN), R1.2
unnamed: IC1.6 (-IN), IC1.7 (OUT), JP1.2
unnamed: D1.K (C), IC1.2 (-IN), R1.1

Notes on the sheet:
Salida SENSOR

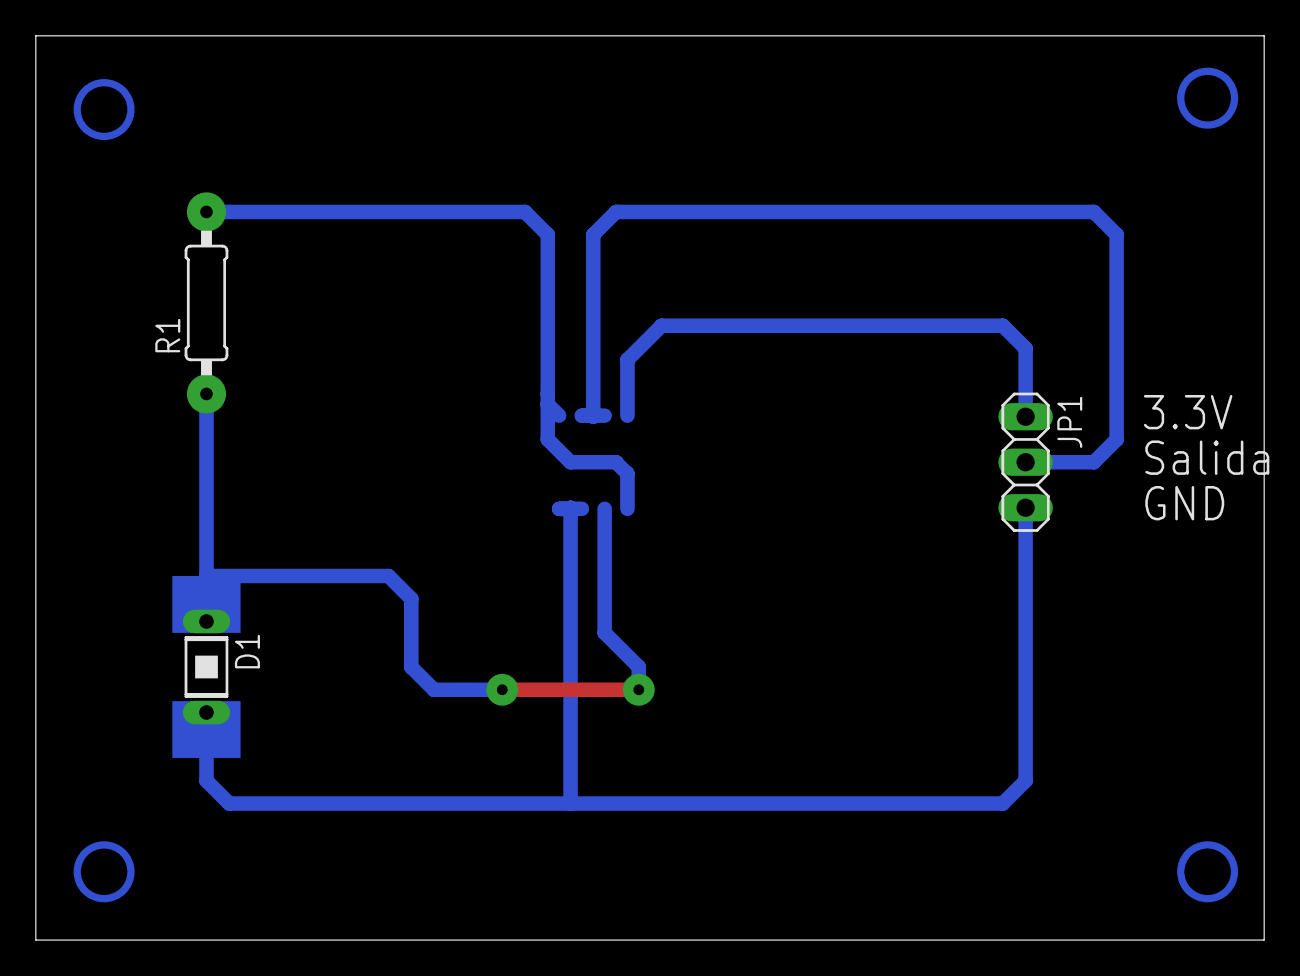
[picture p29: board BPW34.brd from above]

Board: 2 copper layers, 68.6 x 50.5 mm, 4 parts (1 on the bottom side), 5 nets.

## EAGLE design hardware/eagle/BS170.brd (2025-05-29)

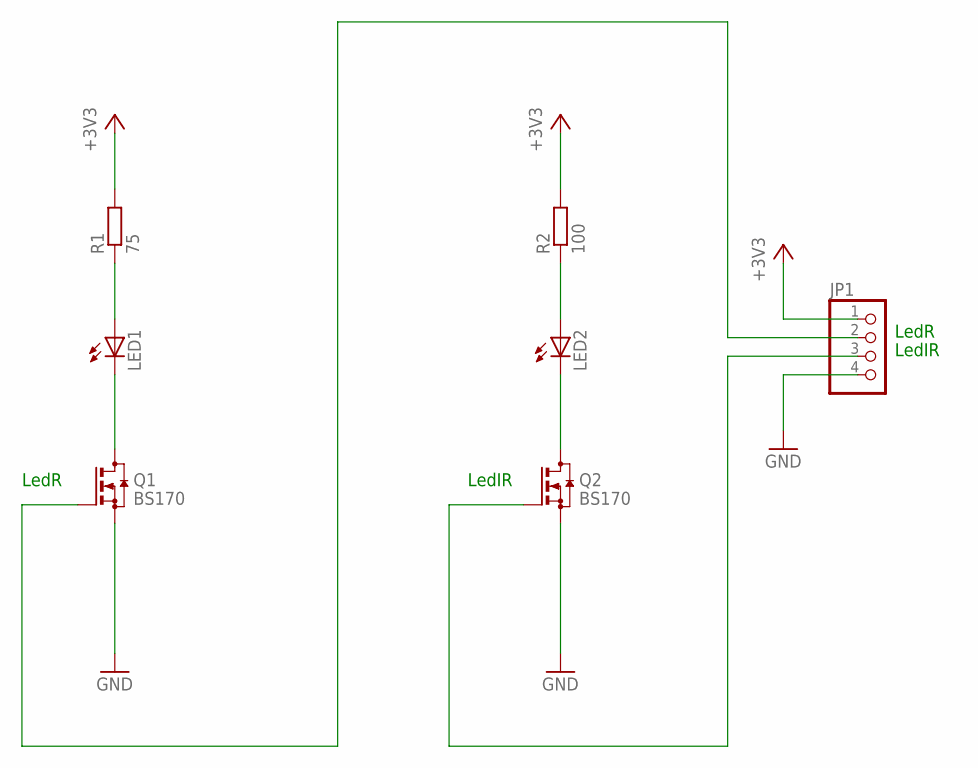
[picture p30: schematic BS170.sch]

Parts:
JP1: PINHD-1X4; 1X04
LED1, LED2: LED5MM
Q1, Q2: BS170; SOT23
R1: 75; 0207/10
R2: 100; 0207/10

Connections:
+3V3: JP1.1, R1.2, R2.2
GND: JP1.4, Q1.2 (S), Q2.2 (S)
unnamed: LED1.A, R1.1
unnamed: LED1.K (C), Q1.3 (D)
unnamed: LED2.A, R2.1
unnamed: LED2.K (C), Q2.3 (D)
unnamed: JP1.3, Q2.1 (G)
unnamed: JP1.2, Q1.1 (G)

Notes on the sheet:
LedIR
LedR

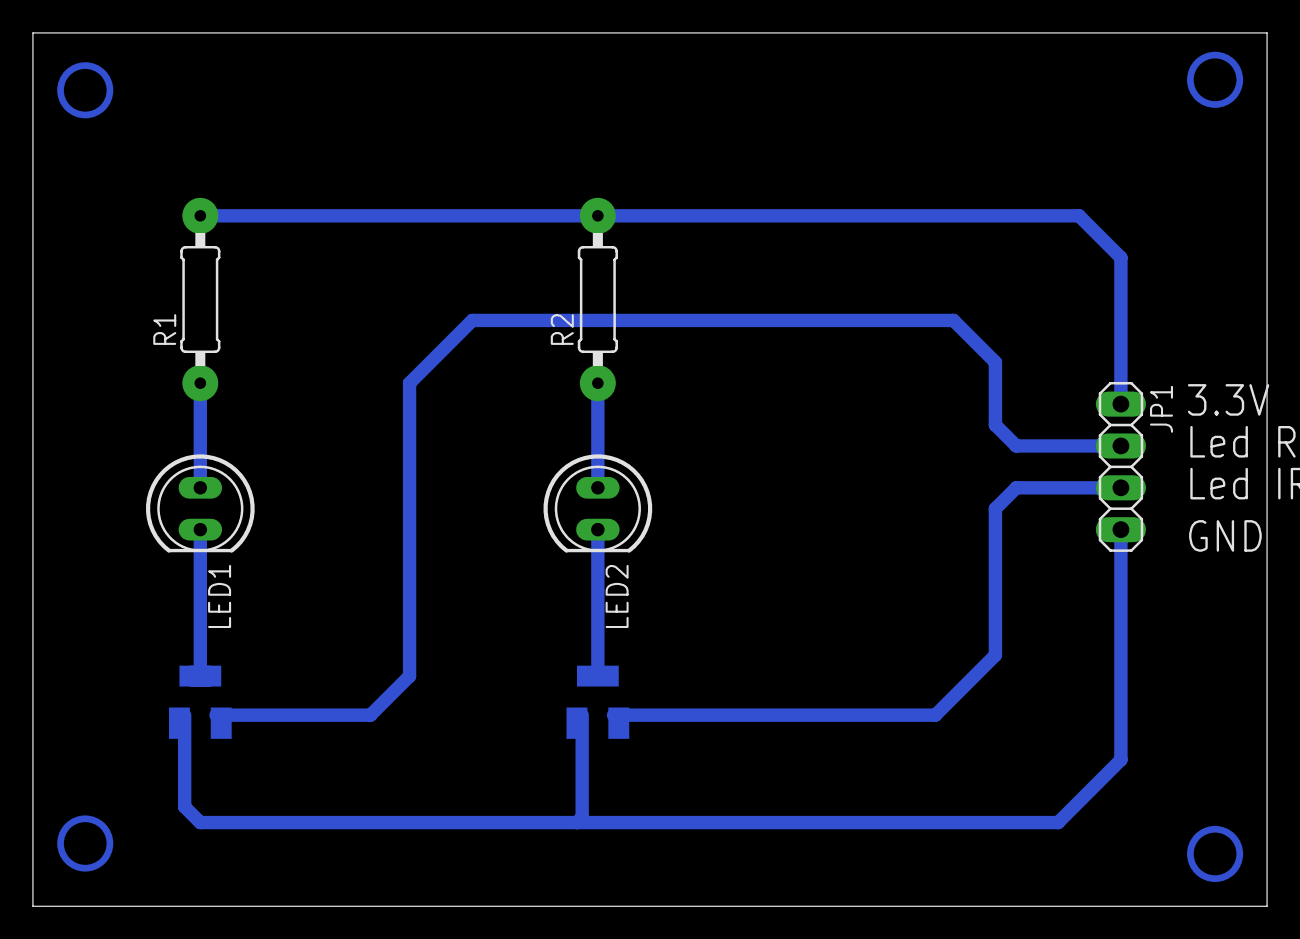
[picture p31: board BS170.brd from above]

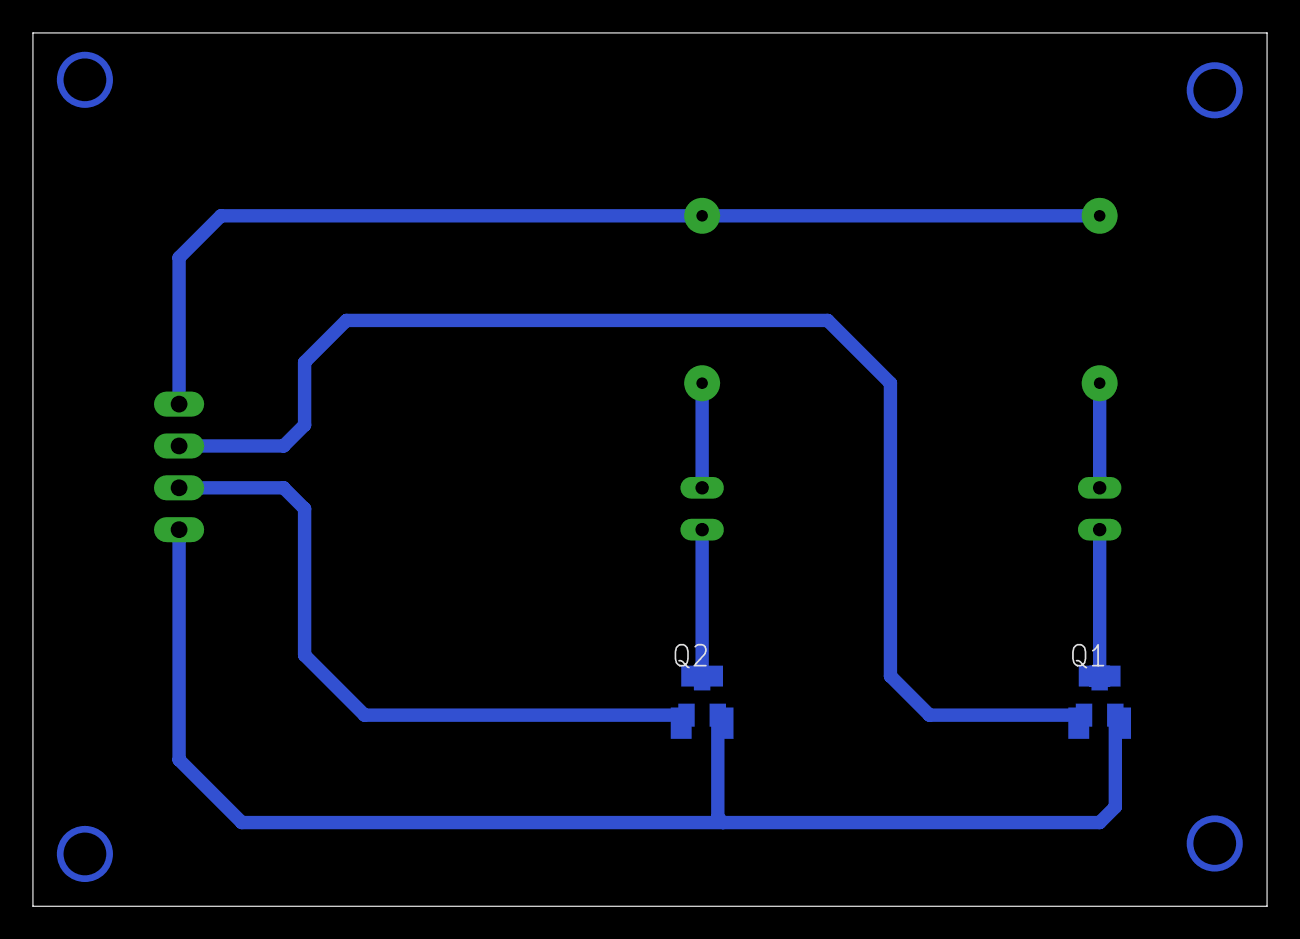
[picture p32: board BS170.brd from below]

Board: 2 copper layers, 74.9 x 53.0 mm, 7 parts (2 on the bottom side), 8 nets.

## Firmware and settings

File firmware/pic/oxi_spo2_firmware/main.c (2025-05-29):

#include "mcc_generated_files/mcc.h"
#include <math.h>
#include <builtins.h>                   // Incluimos librería para trabajar con funciones matemáticas.
#include <math.h>                       // Incluimos librería para trabajar con operaciones matemáticas.
#include "LCD2x16_Library.h"            // Incluimos librería para trabajar con pantalla LCD 16x2.

#define         RED         0           // Asignamos el nombre RED al pin 0.
#define         INFRARED    1           // Asignamos el nombre INFRARED al pin 1.
#define         SignalR     0           // Asignamos el nombre SignalR al pin 0.
#define         SignalIR    1           // Asignamos el nombre SignalIR al pin 1.

/* Variables y arreglos globales  ===================================================================================================
 ==================================================================================================================================*/
uint16_t    tiempo_espera=25;           // Variable que temporizará 25ms.
uint16_t    antR,actR,antIR,actIR;
uint16_t    periodo=0;
uint8_t     subida=0;
uint8_t     pico=0;
float       BPM=0;
float       BPM_prom=0;
float       ratioR, ratioIR;
float       ratio_promR, ratio_promIR;
float       ratio_total;
float       Spo2;
float       vmaxR=0,vminR=0,vmaxIR=0,vminIR=0;
uint8_t     Buffer_LCD[16];             // Arreglo que almacenará el valor numerico con formato a mostrar en la LCD.

/* Función principal  ==============================================================================================================
 ==================================================================================================================================*/
void main(void)
{
    SYSTEM_Initialize();
    ANSELB=0x00;                        // Deshabilitamos las entradas analógicas del puerto B.
    ANSELD=0x00;                        // Deshabilitamos las entradas analógicas del puerto D.
    TRISB=0x00;                         // Configuramos el puerto B como salida.
    TRISC=0x00;                         // Configuramos el puerto C como salida.
    TRISD=0x00;                         // Configuramos el puerto D como salida.
    LATB=0x00;                          // Inicialmente el puerto B estará a nivel bajo.
    Lcd_Init();                         // Llamamos a la fución de configuración de la pantalla LCD.
    Lcd_Clear();                        // Limpiamos la pantalla LCD.
    LATB|=(1<<RED);                     // Inicialmente el pin estará a nivel alto.
    LATB&=~(1<<INFRARED);               // Inicialmente el pin estará a nivel bajo.
    antR=ADC_GetConversion(SignalR);    // Leemos el canal analógico del circuito RED.
    __delay_ms(tiempo_espera);          // Retardo de tiempo.
    LATB&=~(1<<RED);                    // Pin estará a nivel bajo.
    LATB|=(1<<INFRARED);                // Pin estará a nivel alto.
    antIR=ADC_GetConversion(SignalIR);  // Leemos el canal analógico del circuito INFRARED.
    __delay_ms(tiempo_espera);          // Retardo de tiempo.
    
    while (1)                           // Bucle infinito.
    {
        LATB|=(1<<RED);                 // Inicialmente el pin estará a nivel alto.
        LATB&=~(1<<INFRARED);           // Inicialmente el pin estará a nivel bajo.
        actR=ADC_GetConversion(SignalR);// Leemos el canal analógico del circuito RED.
        __delay_ms(tiempo_espera);      // Retardo de tiempo.
        LATB&=~(1<<RED);                // Pin estará a nivel bajo.
        LATB|=(1<<INFRARED);            // Pin estará a nivel alto.
        actIR=ADC_GetConversion(SignalIR);// Leemos el canal analógico del circuito INFRARED.
        
        if(subida==0)
        {
            vminR=antR;
            vminIR=antIR;
        }
        if(actR>antR)
        {
            subida++;                   // Incrementamos en una unidad la variable.
            pico=0;
            if(subida>20)
            {
                subida=20;
            }
        }
        else
        {
            if(subida==20)
            {
                vmaxR=antR;
                vmaxIR=actIR;
            }
            pico=0;
            if(subida>12)
            {
                BPM=(60000/((float)periodo));
                BPM_prom=(BPM_prom)*0.7+(BPM*(1-0.7));
                if(vminR>0 && vmaxR>0 && vminIR>0 && vmaxIR>0)
                {
                   ratioR=abs(log((float)(vminR/vmaxR)));
                   ratioIR=abs(log((float)(vminIR/vmaxIR)));
                   ratio_promR=(ratio_promR*0.7)+(ratioR*(1-0.7));
                   ratio_promIR=(ratio_promIR*0.7)+(ratioIR*(1-0.7));
                   ratio_total=(ratio_promIR/ratio_promR);
                   Spo2=110-(25*ratio_total);
                }
                Lcd_Set_Cursor(1,1);
                sprintf(Buffer_LCD,"%04.2f BPM",BPM_prom);
                Lcd_Write_String(Buffer_LCD);
                Lcd_Set_Cursor(2,1);
                sprintf(Buffer_LCD,"%04.2f Spo2",Spo2);
                Lcd_Write_String(Buffer_LCD);
                periodo=0;
                pico=100;
                subida=0;
            }
        }
        
        antR=actR;
        antIR=actIR;
        __delay_ms(tiempo_espera);
        periodo=periodo+tiempo_espera;
    }
}

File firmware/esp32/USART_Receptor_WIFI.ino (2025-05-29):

/* ESP36 C6 MODO RECEPTOR Y WIFI
*/
#include "ThingSpeak.h"                       // Incluimos librería ThingSpeak para la comunicación con la WEB.
#include "WiFi.h"                             // Incluimos librería WiFi.
#include <LiquidCrystal.h>                    // Incluimos librería LCD.
LiquidCrystal lcd(12, 13, 9, 18, 19, 20);     // Pines de conexicón LCD RS,EN,D4,D5,D6,D7,

/* Vriables y arreglos globales */
char* ssid = "JorgeAPC2.4G";                  // SSID Nombre de la red (ROUTER).
char* password = "45126903@88";               // Contraseña de vuestro ROUTER.

unsigned long channelID =  2439669;           // ID de vuestro canal.
const char* WriteAPIKey = "XRNH44TK2W6ESGXA"; // Write API Key de vuestro canal.         
WiFiClient cliente;

/* Función principal y de configuración */
void setup()
{ 
  Serial.begin(9600);                         // Inicializamos la comunicación USART a 9600
  lcd.begin(16,2);                            // Inicializamos la LCD 16x2.
  WiFi.begin(ssid,password);
  while (WiFi.status() != WL_CONNECTED) {
    delay(500);
    lcd.setCursor(0,1);                       // Cursor fila, columna LCD.
    lcd.print(".");                           // Imprimimos en la LCD el valor de la variable.
  }
  lcd.println("WiFi Connected!");             // Imprimimos mensaje en la LCD.
  ThingSpeak.begin(cliente);                  // Inicializamos la comunicación con ThingSpeak.
}

/* Función buble infinito */
void loop()
{
  float dato1;                                // Variable de almacenamiento de dato transformado.
  dato1 = dato_salida();                      // Lectura del dato arreglado
  lcd.setCursor(0,1);                         // Cursor fila, columna LCD.
  lcd.print(dato1);                           // Imprimimos en la LCD el valor de la variable.
  ThingSpeak.setField (1,dato1);              // Enviamos el dato 1 por WiFi a ThingSpeak.
  //ThingSpeak.setField (2,uvIntensity);      // Enviamos el dato 2 por WiFi a ThingSpeak.
  ThingSpeak.writeFields(channelID,WriteAPIKey);// Para enviar los datos a ThingSpeak se necesita declarar el ID y el Key.
  delay(1000);                                // Retardo 1s. 
}

/* Función dato de salida */
float dato_salida()       
{       
  float dato_flotante = 0;                    // Constructor de dato enviado 
  char vector[20];                            // Variable de almacenamiento de dato leido por serial   
  int flag = 0;                               // Flag de entrada de bucle while
  
  while (flag == 0)                           // Bucle mientras el flag sea menor que 1
  {  
    if (Serial.available())                   // Lectura del puerto serial abierto
    {
      delay(100);                             // Retardo 100ms.
      int i = 0;                              // Variable auxiliar de construccion de vector
      while (Serial.available() > 0)          // Lectura mientras el buffer tenga valores.
      {
        char inByte = Serial.read();          // Variable de almacenamiento de entrada de datos
        vector[i] = inByte;                   // Vector de almacenamiento para construccion de dato
        i+=1;                                 // Incrementamos en una unidad la variable.
        flag=1;                               // Ponenos a 1 la variable.            
      }
      
      dato_flotante = atof(vector);           // Conversión del vector de char a float
      memset(vector, 0, sizeof(vector));      // Limpia los datos ingresados al vector
    }
  } 
  
  return dato_flotante;                       // Retorna el valor arreglado 
}

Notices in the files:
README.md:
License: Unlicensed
